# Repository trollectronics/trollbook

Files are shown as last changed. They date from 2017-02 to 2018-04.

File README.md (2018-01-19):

# Trollbook
*Homebrew 68040 palmtop computer* (http://h4xxel.org/electronics/trollbook/)

This is a work-in-progress palmtop (ish) sized clamshell laptop that we've been
working on for a while.

In its current state, it boots up into a BIOS menu capable of doing
a few simple things like browsing a FAT formatted SD-card, flashing its bootrom
from SD-card and excuting programs from SD-card.
One of the included demo programs can play .MOD music files from SD card.

The entire setup uses about 4.3 Watts while running, including
display and backlight.

The hardware specs as of now can be summed up as following:

 - Motorola 68040FE33V CPU, running at 33 MHz
 - Altera Flex10KA FPGA for glue logic and peripherals (video, uart, spi, audio etc.)
 - Atmel attiny48 for scanning keyboard matrix and mouse, interfacing to I2C peripherals
 - 512 kB of SRAM (used for frame buffer, sound buffer and stage 2 BIOS code)
 - 64 MB of SDRAM
 - 800x480 resolution 7" TFT display, driven at 256 colors (from a 16-bpp palette)
 - Stereo audio DAC, 8 bit/channel, samplerate of 48 kHz
 - SD card interface over SPI
 - On-board SPI Flash ROM (512 kB) for BIOS code
 - 7.4 V, 2.2 Ah battery pack with custom balancing circuitry (which sucks)

The (blue) mainboard is a 10x10 cm 4-layer board, designed by us and manufactured by a Chinese PCB fab.
The larger upper board is a CNC milled peripheral board sporting the keyboard, mouse, IO ports and power supplies.
We desperately need to make a proper case...

## This repository
This repository contains the following:
 - Hardware schematics and layout (kicad)
   - Current Rev 2 motherboard
   - Peripheral board
 - VHDL code for the glue logic/peripheral controller FPGA
 - Source code
   - Stage 1 boot, resides in a small ROM block in the FPGA
   - Stage 2 bios, resides in the large SPI rom
   - Demo code for feature testing/demonstration

## Companion projects
The following projects have been developed for the system:
 - The m68k-emu system emulator (https://github.com/slaeshjag/m68k-emu)
 - The trollos operating system (https://github.com/h4xxel/trollos)

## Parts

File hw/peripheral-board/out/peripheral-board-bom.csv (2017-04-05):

Id | Designator | Package | Quantity | Designation | Supplier and ref
1 | J4001 | Connector_Molex_PicoBlade_53047-0510 | 1 | 53047-0510
2 | J7002 | Connector_Molex_PicoBlade_53047-0410 | 1 | 53047-0310
3 | R2001 | R_1206 | 1 | 0R
4 | C1004,C1003,C7001,C7002,C7005,C7012,C8003,C8004 | C_0805 | 8 | 100n
5 | C7014,C7007,C4001,C4002 | C_1206 | 4 | 1u
6 | R1008,R1009,R1010,R9001,R4006,R8002 | R_0805 | 6 | 47k
7 | R1007,R4004,R4003,R4001,R7008,R7004 | R_0805 | 6 | 10k
8 | D2012,D2011,D2010,D2009,D2008,D2007,D2006,D2005,D2004,D2003,D2013,D2001,D2060,D2051,D2052,D2053,D2002,D2054,D2029,D2016,D2017,D2018,D2019,D2020,D2021,D2028,D2023,D2024,D2025,D2026,D2027,D2032,D2015,D2014,D2022,D2034,D2035,D2036,D2037,D2038,D2039,D2040,D2033,D2042,D2043,D2044,D2045,D2046,D2047,D2048,D2050,D2041,D2049,D2056,D2057,D2058,D2059,D2031,D2061,D2062,D2063,D2064,D2065,D2066,D2067,D2068,D2055,D2030 | D_MiniMELF_Standard | 68 | 1N4148
9 | C1002,C1001 | C_0805 | 2 | C
10 | R1005,R7003,R7007,R7005 | R_0805 | 4 | 100k
11 | U1002 | SOT89-3_Housing | 1 | L78L33ACUTR
12 | C4007,C4004 | TantalC_SizeD_EIA-7343_Reflow | 2 | 100u
13 | L4002 | Choke_SMD_6.3x6.3_H3 | 1 | 10u
14 | L4001 | Choke_SMD_6.3x6.3_H3 | 1 | 8u2
15 | C9001,C4003,C4009 | C_1206 | 3 | 10u
16 | Y5001 | Crystal_Watch | 1 | 32768 Hz
17 | D8001 | LED-3MM | 1 | LED_SD
18 | D1001 | LED-3MM | 1 | LED_PWR
19 | D4003 | LED-5MM-3 | 1 | SSL-LX3059IGW-CA
20 | R8003,R1006 | R_0805 | 2 | 1k
21 | Q8001 | SOT-23 | 1 | BSS84LT1G
22 | R4005 | R_1812 | 1 | 0R05
23 | C7004,C7008,C7015 | c_elec_8x6.7 | 3 | 220u
24 | C7003,C7011 | c_elec_6.3x5.8 | 2 | 10u
25 | C4011,C4010 | c_elec_6.3x5.8 | 2 | 100u
26 | L4003 | Choke_SMD_12x12mm_h6mm | 1 | 47u
27 | Q4001 | SOT-23 | 1 | IRLML2244TRPbF
28 | R1003,R1004,R1002,R1001 | R_0805 | 4 | R
29 | RP2001 | R_Cat16-4 | 1 | 10k
30 | CONN9001 | 10056847-XY1LF | 1 | 10056847-XY1LF
31 | U1001 | TQFP-32_7x7mm_Pitch0.8mm | 1 | ATTINY48-A
32 | R4013 | R_0805 | 1 | 13.3k
33 | R4009 | R_0805 | 1 | 412k
34 | R4008 | R_0805 | 1 | 51k
35 | R4007 | R_0805 | 1 | 626k
36 | R4002 | R_0805 | 1 | 330k
37 | R4012 | R_0805 | 1 | 270k
38 | C7006,C7013,C8002 | C_0805 | 3 | 1u
39 | C7016,C7009 | C_0805 | 2 | 1n
40 | C7010,C7017 | C_0805 | 2 | 47n
41 | U7002,U7001 | SOIC-8_3.9x4.9mm_Pitch1.27mm | 2 | LM386
42 | U7003,U7004 | SOIC-8_3.9x4.9mm_Pitch1.27mm | 2 | MCP4011
43 | R7009,R7006 | R_0805 | 2 | 10
44 | J7001 | FCR1295 | 1 | FCR1295
45 | CON8001 | TS-2198-01 | 1 | SD_Card
46 | CON4001 | JACK_ALIM | 1 | BARREL_JACK
47 | C4008 | C_0805 | 1 | 120p
48 | C4005 | C_0805 | 1 | 680n
49 | C4006 | C_1206 | 1 | 2.2u
50 | D4006 | D_MiniMELF_Standard | 1 | 1n4148
51 | D4007 | D_SOD-323 | 1 | NSR0530HT1G
52 | D4005,D4001,D4008,D4002 | D_TUMD2 | 4 | RBE2VA20ATR
53 | U4001 | SOIC-8_3.9x4.9mm_Pitch1.27mm | 1 | AP1509
54 | U4003 | MSOP-12-1EP_3x4mm_Pitch0.65mm | 1 | LT3652
55 | U4002 | SOT-23-5 | 1 | LM27313
56 | C5001,C5002 | C_0603 | 2 | 22p
57 | U5001 | SOIC-8_3.9x4.9mm_Pitch1.27mm | 1 | MCP7940N
58 | SW1001 | SMD-TACT-5.2x5.2x2mm | 1 | Power
59 | U3001 | PSPNUB | 1 | PSPNUB
60 | SW2069,SW2065 | SMD-TACT-5.2x5.2x2mm | 2 | SPACE
61 | P1002 | Socket_Strip_Straight_1x04 | 1 | Power
62 | P1001 | Socket_Strip_Straight_1x29 | 1 | Peripheral Bus
63 | U2003 | SOIC-14_3.9x8.7mm_Pitch1.27mm | 1 | 74HC00
64 | U2001,U2002 | SOIC-16_3.9x9.9mm_Pitch1.27mm | 2 | 4017
65 | SW2001 | SMD-TACT-5.2x5.2x2mm | 1 | 1
66 | SW2002 | SMD-TACT-5.2x5.2x2mm | 1 | 2
67 | SW2003 | SMD-TACT-5.2x5.2x2mm | 1 | 3
68 | SW2004 | SMD-TACT-5.2x5.2x2mm | 1 | 4
69 | SW2005 | SMD-TACT-5.2x5.2x2mm | 1 | 5
70 | SW2006 | SMD-TACT-5.2x5.2x2mm | 1 | 6
71 | SW2007 | SMD-TACT-5.2x5.2x2mm | 1 | 7
72 | SW2009 | SMD-TACT-5.2x5.2x2mm | 1 | 9
73 | SW2035 | SMD-TACT-5.2x5.2x2mm | 1 | A
74 | SW2010 | SMD-TACT-5.2x5.2x2mm | 1 | 0
75 | SW2011 | SMD-TACT-5.2x5.2x2mm | 1 | +
76 | SW2012 | SMD-TACT-5.2x5.2x2mm | 1 | ´
77 | SW2013 | SMD-TACT-5.2x5.2x2mm | 1 | BKSP
78 | SW2014 | SMD-TACT-5.2x5.2x2mm | 1 | TROLL
79 | SW2015 | SMD-TACT-5.2x5.2x2mm | 1 | §
80 | SW2008 | SMD-TACT-5.2x5.2x2mm | 1 | 8
81 | SW2016 | SMD-TACT-5.2x5.2x2mm | 1 | UP
82 | SW2019 | SMD-TACT-5.2x5.2x2mm | 1 | W
83 | SW2020 | SMD-TACT-5.2x5.2x2mm | 1 | E
84 | SW2021 | SMD-TACT-5.2x5.2x2mm | 1 | R
85 | SW2022 | SMD-TACT-5.2x5.2x2mm | 1 | T
86 | SW2023 | SMD-TACT-5.2x5.2x2mm | 1 | Y
87 | SW2024 | SMD-TACT-5.2x5.2x2mm | 1 | U
88 | SW2033 | SMD-TACT-5.2x5.2x2mm | 1 | LEFT
89 | SW2017 | SMD-TACT-5.2x5.2x2mm | 1 | RMB
90 | SW2027 | SMD-TACT-5.2x5.2x2mm | 1 | P
91 | SW2028 | SMD-TACT-5.2x5.2x2mm | 1 | Å
92 | SW2029 | SMD-TACT-5.2x5.2x2mm | 1 | ¨
93 | SW2030 | SMD-TACT-5.2x5.2x2mm | 1 | RETURN
94 | SW2031 | SMD-TACT-5.2x5.2x2mm | 1 | ALT_GR
95 | SW2032 | SMD-TACT-5.2x5.2x2mm | 1 | <
96 | SW2034 | SMD-TACT-5.2x5.2x2mm | 1 | MMB
97 | SW2025 | SMD-TACT-5.2x5.2x2mm | 1 | I
98 | SW2037 | SMD-TACT-5.2x5.2x2mm | 1 | D
99 | SW2038 | SMD-TACT-5.2x5.2x2mm | 1 | F
100 | SW2039 | SMD-TACT-5.2x5.2x2mm | 1 | G
101 | SW2040 | SMD-TACT-5.2x5.2x2mm | 1 | H
102 | SW2041 | SMD-TACT-5.2x5.2x2mm | 1 | J
103 | SW2042 | SMD-TACT-5.2x5.2x2mm | 1 | K
104 | SW2043 | SMD-TACT-5.2x5.2x2mm | 1 | L
105 | SW2018 | SMD-TACT-5.2x5.2x2mm | 1 | Q
106 | SW2045 | SMD-TACT-5.2x5.2x2mm | 1 | Ä
107 | SW2046 | SMD-TACT-5.2x5.2x2mm | 1 | '
108 | SW2047 | SMD-TACT-5.2x5.2x2mm | 1 | ESC
109 | SW2048 | SMD-TACT-5.2x5.2x2mm | 1 | TAB
110 | SW2049 | SMD-TACT-5.2x5.2x2mm | 1 | ALT
111 | SW2050 | SMD-TACT-5.2x5.2x2mm | 1 | DOWN
112 | SW2052 | SMD-TACT-5.2x5.2x2mm | 1 | SHIFT_L
113 | SW2026 | SMD-TACT-5.2x5.2x2mm | 1 | O
114 | SW2044 | SMD-TACT-5.2x5.2x2mm | 1 | Ö
115 | SW2061 | SMD-TACT-5.2x5.2x2mm | 1 | .
116 | SW2053 | SMD-TACT-5.2x5.2x2mm | 1 | Z
117 | SW2054 | SMD-TACT-5.2x5.2x2mm | 1 | X
118 | SW2055 | SMD-TACT-5.2x5.2x2mm | 1 | C
119 | SW2056 | SMD-TACT-5.2x5.2x2mm | 1 | V
120 | SW2057 | SMD-TACT-5.2x5.2x2mm | 1 | B
121 | SW2058 | SMD-TACT-5.2x5.2x2mm | 1 | N
122 | SW2059 | SMD-TACT-5.2x5.2x2mm | 1 | M
123 | SW2051 | SMD-TACT-5.2x5.2x2mm | 1 | LMB
124 | SW2036 | SMD-TACT-5.2x5.2x2mm | 1 | S
125 | SW2062 | SMD-TACT-5.2x5.2x2mm | 1 | -
126 | SW2063 | SMD-TACT-5.2x5.2x2mm | 1 | SHIFT_R
127 | SW2064 | SMD-TACT-5.2x5.2x2mm | 1 | FN_R
128 | SW2066 | SMD-TACT-5.2x5.2x2mm | 1 | FN_L
129 | SW2067 | SMD-TACT-5.2x5.2x2mm | 1 | RIGHT
130 | SW2068 | SMD-TACT-5.2x5.2x2mm | 1 | CTRL
131 | SW2060 | SMD-TACT-5.2x5.2x2mm | 1 | ,

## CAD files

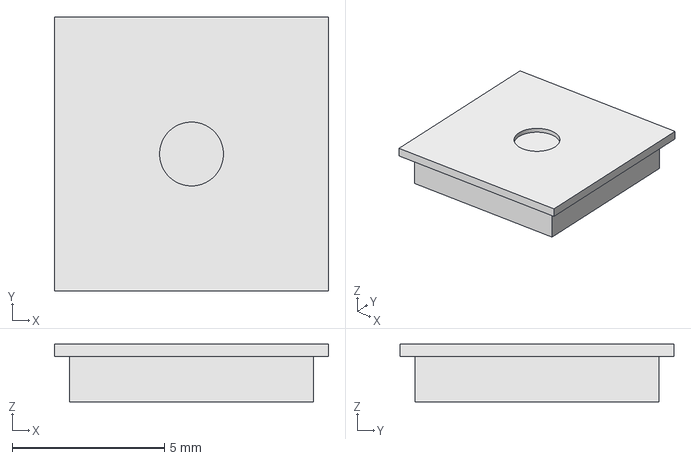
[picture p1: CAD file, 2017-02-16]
cad/keyboard_prototype/keycap.fcstd
9.00 x 9.00 x 1.90 mm

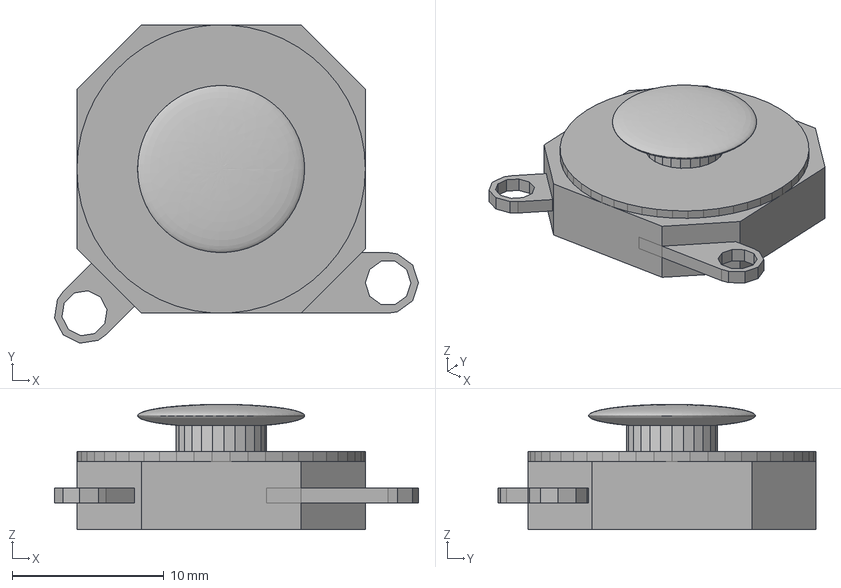
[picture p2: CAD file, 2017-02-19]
hw/peripheral-board/3d/pspnub.step
24.0 x 21.0 x 8.25 mm

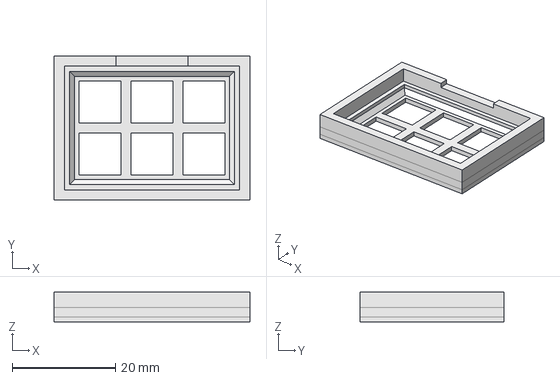
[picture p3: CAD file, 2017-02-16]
cad/keyboard_prototype/keyboard_frame.fcstd
38.0 x 28.0 x 5.80 mm

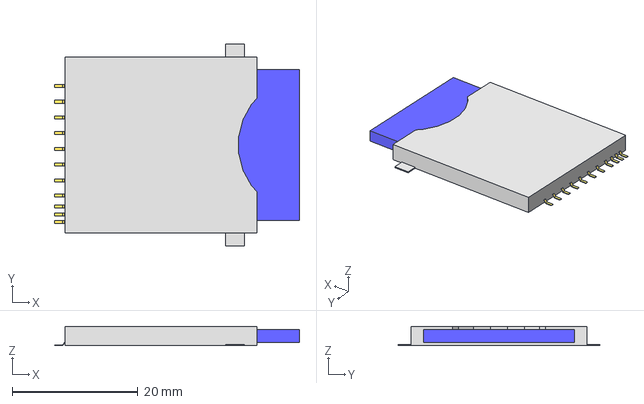
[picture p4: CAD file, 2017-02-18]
hw/peripheral-board/3d/SD-RSMT-2-MQ.step
39.0 x 32.1 x 3.10 mm

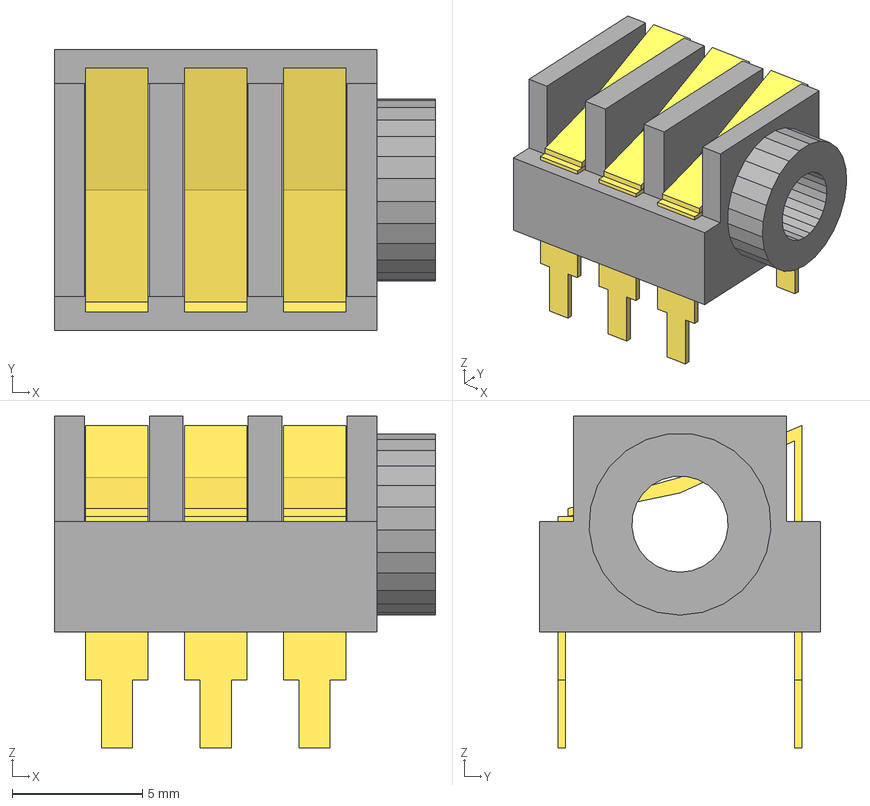
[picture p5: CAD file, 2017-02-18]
hw/peripheral-board/3d/FCR1295.step
14.7 x 10.8 x 12.8 mm

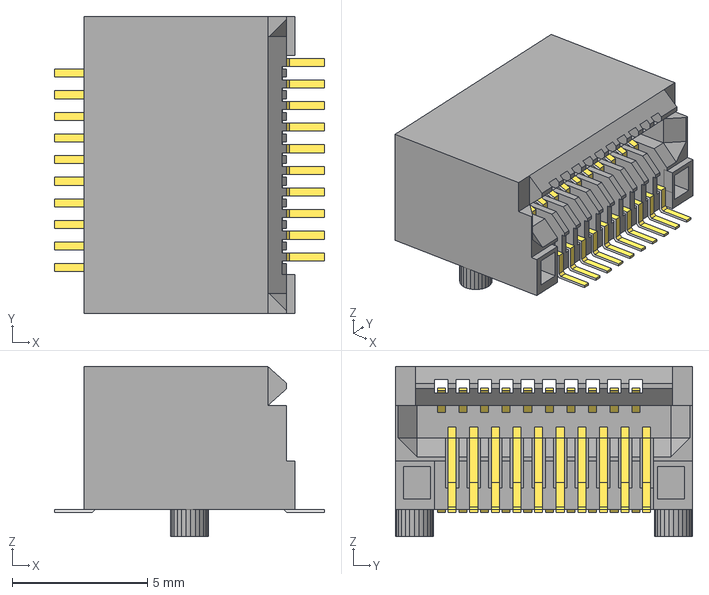
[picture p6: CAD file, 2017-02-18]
hw/peripheral-board/3d/10056847-XY1LF.step
10.0 x 11.0 x 6.30 mm

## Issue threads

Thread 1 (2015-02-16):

sram has wrong footprint

h4xxel, 2015-02-16:
i am retarded

Closed 2016-04-02.

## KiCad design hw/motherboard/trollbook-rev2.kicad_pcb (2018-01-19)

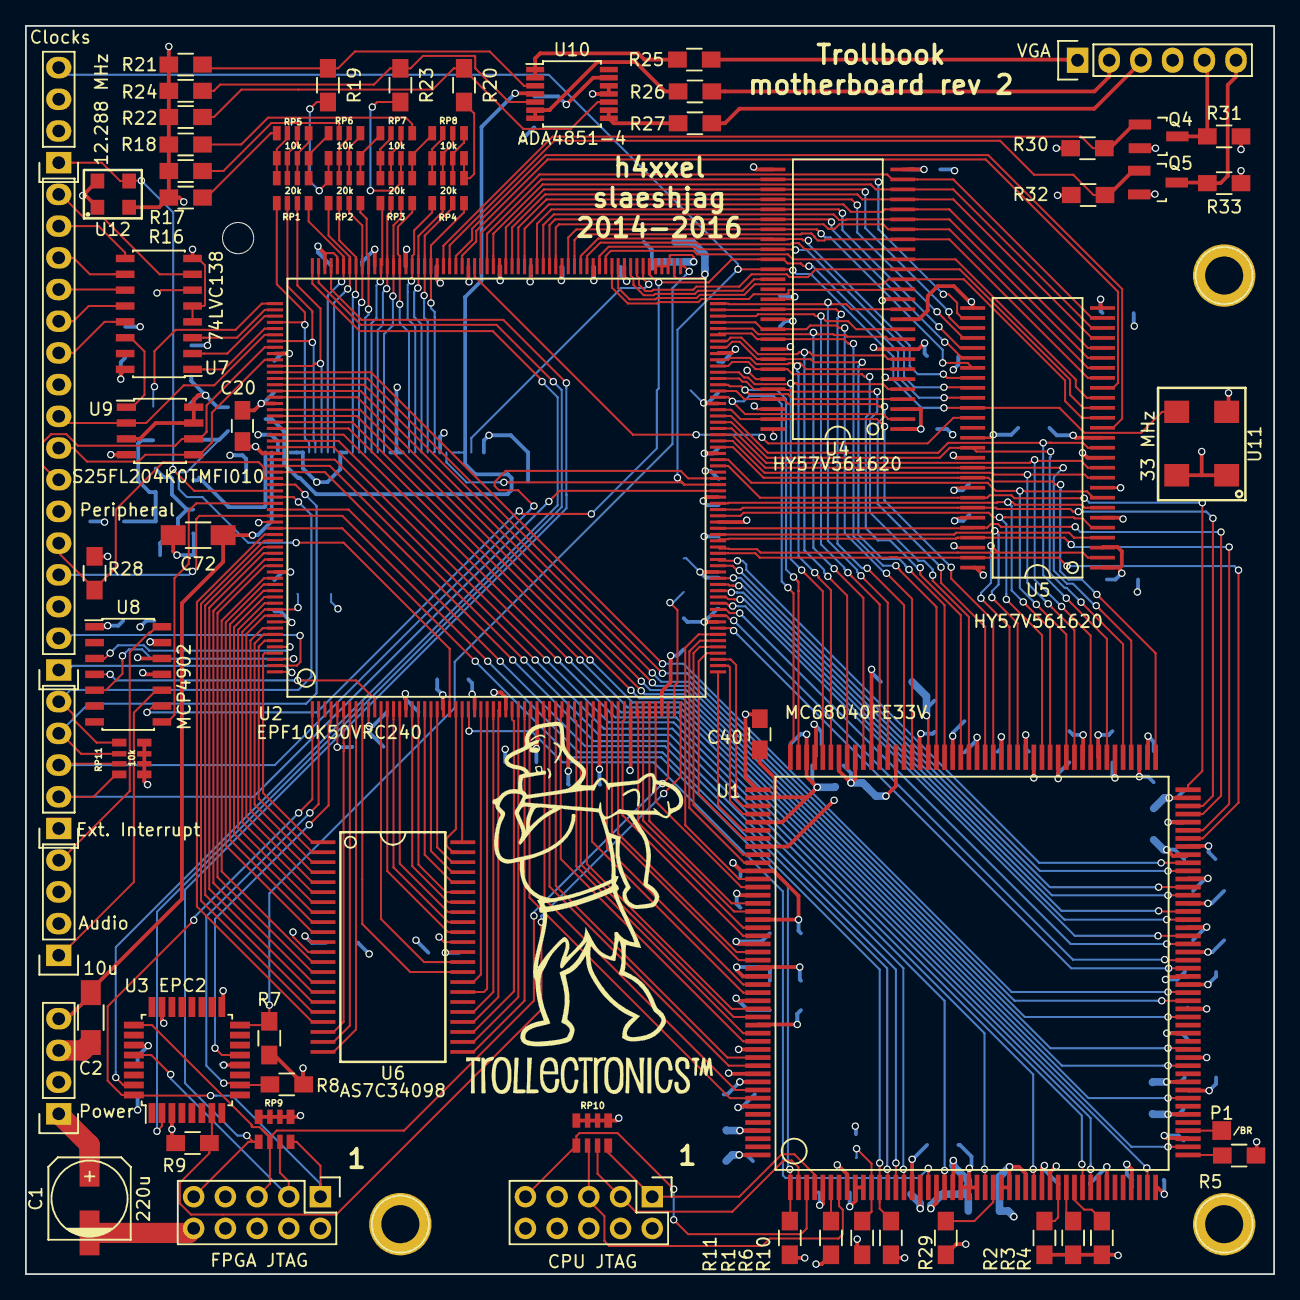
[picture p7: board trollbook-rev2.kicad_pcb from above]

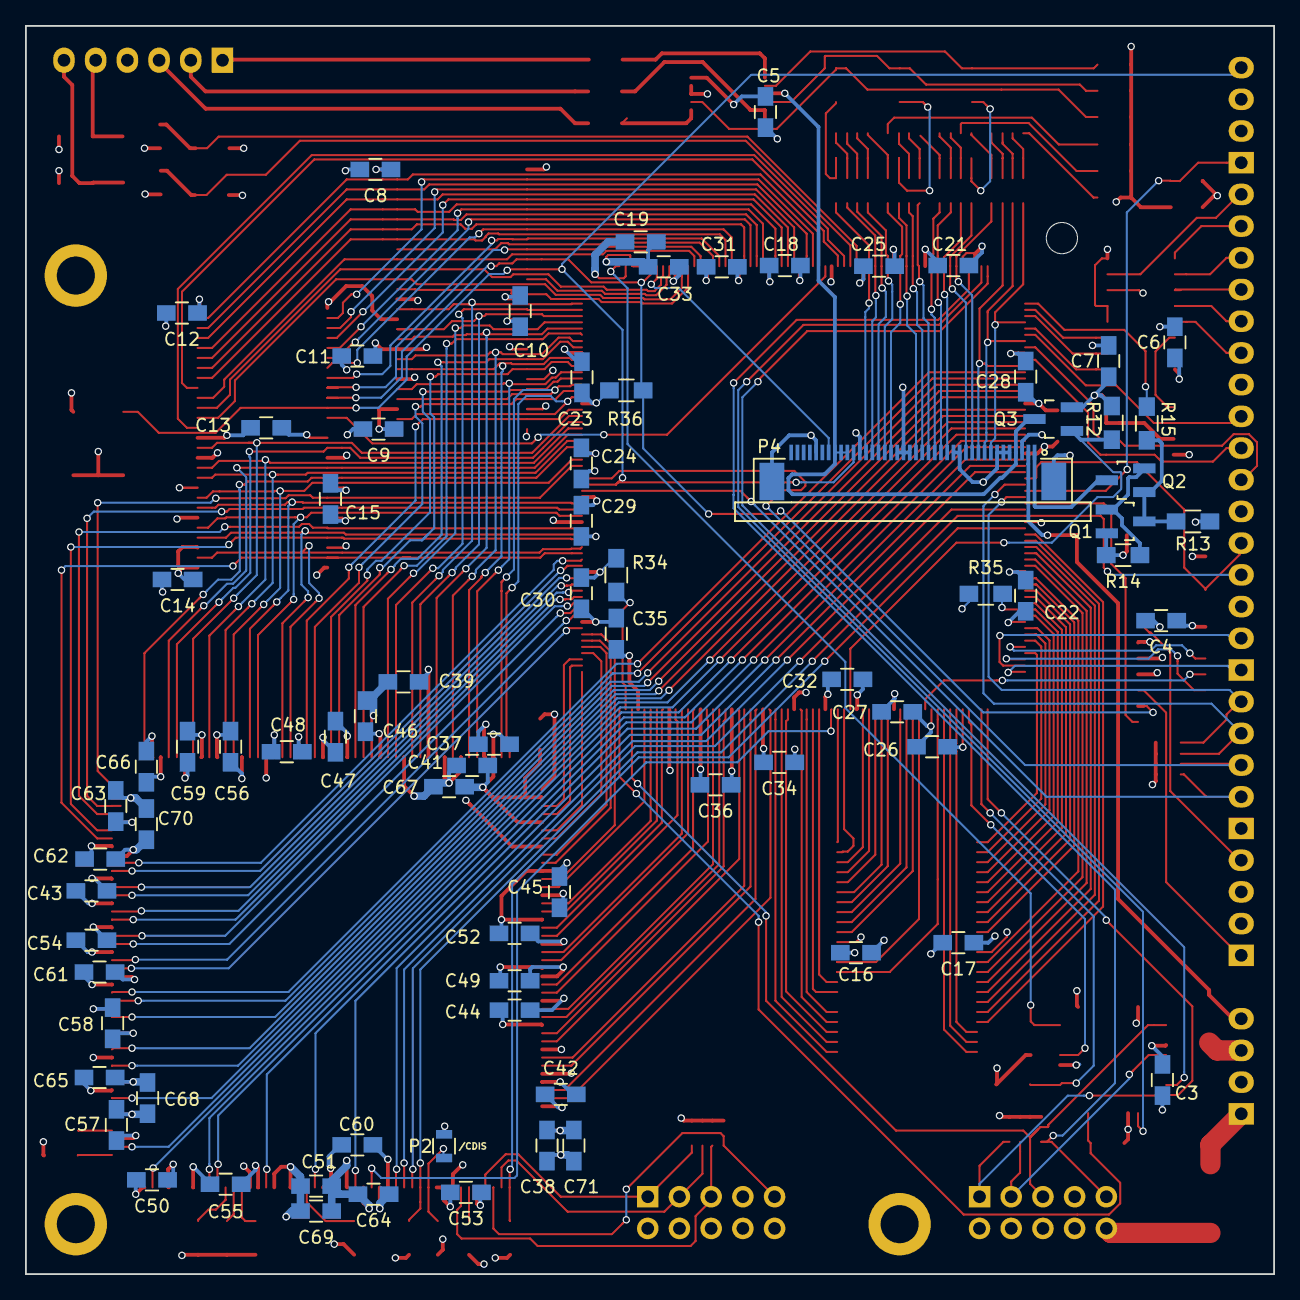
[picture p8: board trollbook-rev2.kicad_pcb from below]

Board: 4 copper layers, 100.0 x 100.0 mm, 147 parts (79 on the bottom side), 258 nets.

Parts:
C1: 220u; c_elec_6.3x7.7
C2: 10u; C_1206_HandSoldering
C3, C4, C5, C6, C7, C8, C9, C10, C11, C12, C13, C14, C15, C16, C17, C18, C19, C20, C21, C22, C23, C24, C25, C26, C27, C28, C29, C30, C31, C32, C33, C34, C35, C36, C67, C68, C69, C70, C71: 100n; C_0805_HandSoldering
C37, C38, C39, C40, C41, C42, C43, C44, C45, C46, C47, C48, C49, C50, C51, C52, C53, C54, C55, C56, C57, C58, C59, C60, C61, C62, C63, C64, C65, C66: 10n; C_0805_HandSoldering
C72: 1u; C_1206_HandSoldering
CON1: FPGA JTAG; Pin_Header_Straight_2x05
CON2: CPU JTAG; Pin_Header_Straight_2x05
P1: /BR; Measurement_Point_Square-SMD-Pad_Small
P2: /CDIS; R_0805
P3: Audio; Pin_Header_Straight_1x04
P4: ER-CON40HT-1
P5: Power; Pin_Header_Straight_1x04
P6: Peripheral; Pin_Header_Straight_1x16
P7: VGA; Pin_Header_Straight_1x06
P8: Clocks; Pin_Header_Straight_1x04
P9: Ext. Interrupt; Pin_Header_Straight_1x05
Q1, Q2, Q4, Q5: 2N7002E; SOT-23_Handsoldering
Q3: DMP3030SN-7; SOT-23_Handsoldering
R1, R10, R11, R15, R29, R30, R31, R32, R33: R; R_0805_HandSoldering
R2, R3, R4, R5, R6, R12, R16, R17, R18, R34, R35, R36: 10k; R_0805_HandSoldering
R7, R8, R9, R28: 1k; R_0805_HandSoldering
R13: 470k; R_0805_HandSoldering
R14: 20R; R_0805_HandSoldering
R19, R20, R23: 560k; R_0805_HandSoldering
R21, R22, R24: 180k; R_0805_HandSoldering
R25, R26, R27: 75; R_0805_HandSoldering
RP1, RP2, RP3, RP4: 20k; RPACK8_SMD
RP5, RP6, RP7, RP8, RP9, RP10, RP11: 10k; RPACK8_SMD
U1: MC68040FE33V; QFP-184
U2: EPF10K50VRC240; RQFP-240
U3: EPC2; TQFP-32_7x7mm_Pitch0.8mm
U4, U5: HY57V561620; TSOP54
U6: AS7C34098; TSOP44
U7: 74LVC138; SOIC-16_3.9x9.9mm_Pitch1.27mm
U8: MCP4902; SOIC-14_3.9x8.7mm_Pitch1.27mm
U9: S25FL204K0TMFI010; SOIC-8_3.9x4.9mm_Pitch1.27mm
U10: ADA4851-4; TSSOP-14_4.4x5mm_Pitch0.65mm
U11: 33 MHz; OSC-VCC1-B3B
U12: 12.288 MHz; OSC-ASFLMB

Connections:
+3V3: C1.1, C3.1, C4.1, C5.1, C6.1, C7.1, C8.1, C9.1, C10.1, C11.1, C12.1, C13.1, C14.1, C15.1, C16.1, C17.1, C18.1, C19.1, C20.1, C21.1, C22.1, C23.2, C24.2, C25.2, C26.2, C27.2, C28.1, C29.1, C30.1, C31.1, C32.1, C33.2, C34.2, C35.2, C36.2, C37.1, C38.1, C39.1, C40.1, C41.1, C42.2, C43.2, C44.2, C45.2, C46.2, C47.1, C48.1, C49.1, C50.1, C51.1, C52.2, C53.2, C54.2, C55.2, C56.2, C57.1, C58.1, C59.1, C60.1, C61.1, C62.2, C63.2, C64.2, C65.2, C66.2, C67.1, C68.1, C69.1, C70.1, C71.1, CON1.4, CON2.4, P5.1, Q3.2, R5.1, R6.2, R7.1, R8.1, R9.1, R11.1, R15.1, R29.1, R30.2, R31.2, R32.2, R33.2, R34.1, R35.1, RP9.1, RP9.2, RP9.3, RP9.4, RP10.1, RP10.2, RP10.3, RP10.4, RP11.1, RP11.2, RP11.3, RP11.4, U1.9, U1.10, U1.16, U1.19, U1.21, U1.32, U1.43, U1.49, U1.56, U1.62, U1.69, U1.75, U1.81, U1.84, U1.88, U1.94, U1.100, U1.102, U1.109, U1.115, U1.122, U1.128, U1.136, U1.140, U1.143, U1.149, U1.155, U1.161, U1.168, U1.175, U1.181, U2.5, U2.16, U2.27, U2.37, U2.47, U2.57, U2.77, U2.89, U2.96, U2.112, U2.122, U2.130, U2.140, U2.150, U2.160, U2.170, U2.189, U2.205, U2.224, U3.3, U3.17, U3.23, U3.27, U4.1, U4.3, U4.9, U4.14, U4.27, U4.43, U4.49, U5.1, U5.3, U5.9, U5.14, U5.27, U5.43, U5.49, U6.11, U6.33, U7.6, U7.16, U8.1, U8.11, U8.13, U9.3, U9.7, U9.8, U10.13, U11.1, U11.4, U12.1, U12.4
/A0: U1.70, U2.68
/A1: U1.71, U2.70
/A2: U1.73, U2.71
/A3: U1.74, U2.72
/A4: U1.76, U2.73
/A5: U1.77, U2.74
/A6: U1.79, U2.75
/A7: U1.80, U2.76
/A8: U1.82, U2.78
/A9: U1.83, U2.79
/A10: U1.173, U2.39
/A11: U1.172, U2.40
/A12: U1.170, U2.41
/A13: U1.169, U2.43
/A14: U1.167, U2.44
/A15: U1.166, U2.45
/A16: U1.164, U2.46
/A17: U1.163, U2.48
/A18: U1.160, U2.49
/A19: U1.159, U2.50
/A20: U1.157, U2.51
/A21: U1.156, U2.53
/A22: U1.154, U2.54
/A23: U1.153, U2.55
/A24: U1.151, U2.56
/A25: U1.150, U2.67
/A26: U1.148, U2.66
/A27: U1.147, U2.65
/A28: U1.145, U2.64
/A29: U1.144, U2.61
/A30: U1.142, U2.62
/A31: U1.141, U2.63
/AUDIOL: P3.4, U8.14
/AUDIOR: P3.1, U8.10
/CLK12: P8.1, U2.211, U12.3
/CLK33: P4.30, P8.4, U2.91, U4.38, U5.38, U11.3
/CONF_CLK: U2.179, U3.2
/CONF_CS: R8.2, U2.2, U3.10
/CONF_DATA: U2.180, U3.31
/CONF_INIT: R7.2, U2.121, U3.16
/CONF_OE: R9.2, U2.60, U3.7
/CONF_TDO: CON1.3, RP9.7, U3.28
/CPUBB: R5.2, U1.47
/CPUBG: R4.2, U1.36
/CPUBR: P1.1, U1.50
/CPUCDIS: P2.1, R6.1, U1.11
/CPUCLK: U1.18, U2.26
/CPUIPL0: U1.15, U2.207
/CPUIPL1: U1.14, U2.208
/CPUIPL2: U1.13, U2.214
/CPULFO: U1.20, U2.206
/CPULOC: R1.2, U1.6
/CPURSTI: P6.4, R10.2, U1.12, U2.215
/CPURSTO: R11.2, U1.1, U2.217
/CPURW: U1.58, U2.196
/CPUSC0: R2.2, U1.34
/CPUSC1: R3.2, U1.35
/CPUSCD: U1.25, U2.204
/CPUSIZ0: U1.60, U2.195
/CPUSIZ1: U1.54, U2.198
/CPUTA: U1.38, U2.201
/CPUTBI: U1.31, U2.203
/CPUTCK: CON2.1, RP10.8, U1.4
/CPUTDI: CON2.9, RP10.5, U1.3
/CPUTDO: CON2.3, RP10.7, U1.2
/CPUTEA: U1.37, U2.202
/CPUTIP: U1.45, U2.200
/CPUTM0: U1.64, U2.194
/CPUTM1: U1.66, U2.193
/CPUTM2: U1.67, U2.192
/CPUTMS: CON2.5, RP10.6, U1.7
/CPUTP: U1.48, U2.199
/CPUTT0: U1.177, U2.36
/CPUTT1: U1.176, U2.38
/D0: U1.138, U2.105, U4.2
/D1: U1.137, U2.107, U4.4
/D2: U1.134, U2.109, U4.5
/D3: U1.133, U2.111, U4.7
/D4: U1.131, U2.114, U4.8
/D5: U1.129, U2.116, U4.10
/D6: U1.127, U2.118, U4.11
/D7: U1.126, U2.120, U4.13
/D8: U1.124, U2.119, U4.42
/D9: U1.123, U2.117, U4.44
/D10: U1.120, U2.115, U4.45
/D11: U1.119, U2.113, U4.47
/D12: U1.117, U2.110, U4.48
/D13: U1.116, U2.108, U4.50
/D14: U1.114, U2.106, U4.51
/D15: U1.113, U2.103, U4.53
/D16: U1.111, U2.81, U5.2
/D17: U1.110, U2.83, U5.4
/D18: U1.107, U2.86, U5.5
/D19: U1.106, U2.88, U5.7
/D20: U1.104, U2.95, U5.8
/D21: U1.103, U2.98, U5.10
/D22: U1.101, U2.100, U5.11
/D23: U1.99, U2.102, U5.13
/D24: U1.97, U2.101, U5.42
/D25: U1.96, U2.99, U5.44
/D26: U1.93, U2.97, U5.45
/D27: U1.92, U2.94, U5.47
/D28: U1.90, U2.87, U5.48
/D29: U1.89, U2.84, U5.50
/D30: U1.87, U2.82, U5.51
/D31: U1.86, U2.80, U5.53
/EXTINT0: P9.2, RP11.8, U2.90
/EXTINT1: P9.3, RP11.7, U2.92
/EXTINT2: P9.4, RP11.6, U2.210
/EXTINT3: P9.5, RP11.5, U2.212
/FPGA_TCK: CON1.1, RP9.8, U2.1, U3.32
/FPGA_TDI: CON1.9, RP9.5, U2.177
/FPGA_TDO: U2.4, U3.13
/FPGA_TMS: CON1.5, RP9.6, U2.58, U3.25
/LLA1: U2.237, U6.1
/LLA2: U2.235, U6.2
/LLA3: U2.234, U6.3
/LLA4: U2.233, U6.4
/LLA5: U2.231, U6.5
/LLA6: U2.219, U6.18
/LLA7: U2.218, U6.19
/LLA8: U2.6, U6.20
/LLA9: U2.7, U6.21
/LLA10: U2.8, U6.22
/LLA11: U2.35, U6.23
/LLA12: U2.34, U6.24
/LLA13: U2.33, U6.25
/LLA14: U2.31, U6.26
/LLA15: U2.30, U6.27
/LLA16: U2.21, U6.42
/LLA17: U2.24, U6.43
/LLA18: U2.25, U6.44
/LLCE: R35.2, U2.230, U6.6
/LLD0: U2.229, U6.7
/LLD1: U2.228, U6.8
/LLD2: U2.227, U6.9
/LLD3: U2.226, U6.10
/LLD4: U2.225, U6.13
/LLD5: U2.223, U6.14
/LLD6: U2.222, U6.15
/LLD7: U2.221, U6.16
/LLD8: U2.29, U6.29
/LLD9: U2.28, U6.30
/LLD10: U2.9, U6.31
/LLD11: U2.12, U6.32
/LLD12: U2.13, U6.35
/LLD13: U2.14, U6.36
/LLD14: U2.15, U6.37
/LLD15: U2.17, U6.38
/LLLB: U2.18, U6.39
/LLOE: U2.20, U6.41
/LLUB: U2.19, U6.40
/LLWE: U2.220, U6.17
/PWRON_RESET: P6.5, R28.1, U2.209
/RAM0CS: U2.136, U4.19
/RAM0LDQM: U2.132, U4.15
/RAM0UDQM: U2.129, U4.39
/RAM1CS: U2.156, U5.19
/RAM1LDQM: U2.157, U5.15
/RAM1UDQM: U2.154, U5.39
/RAMA0: U2.146, U4.23, U5.23
/RAMA1: U2.148, U4.24, U5.24
/RAMA2: U2.151, U4.25, U5.25
/RAMA3: U2.153, U4.26, U5.26
/RAMA4: U2.152, U4.29, U5.29
/RAMA5: U2.149, U4.30, U5.30
/RAMA6: U2.147, U4.31, U5.31
/RAMA7: U2.144, U4.32, U5.32
/RAMA8: U2.142, U4.33, U5.33
/RAMA9: U2.139, U4.34, U5.34
/RAMA10: U2.143, U4.22, U5.22
/RAMA11: U2.137, U4.35, U5.35
/RAMA12: U2.134, U4.36, U5.36
/RAMB0: U2.138, U4.20, U5.20
/RAMB1: U2.141, U4.21, U5.21
/RAMCAS: U2.128, U4.17, U5.17
/RAMCKE: R36.1, U2.126, U4.37, U5.37, U8.9
/RAMRAS: U2.133, U4.18, U5.18
/RAMWE: U2.131, U4.16, U5.16
/SNDSYNC: U2.213, U8.8
/SPI0CLK: P6.7, U2.188, U9.6
/SPI0MISO: P6.9, U2.186, U9.2
/SPI0MOSI: P6.8, U2.190, U9.5
/SPI0SS1: U7.14, U9.1
/SPI0SS2: P6.11, U7.13
/SPI0SS3: P6.12, U7.12
/SPI0SS4: P6.13, U7.11
/SPI0SS5: P6.14, U7.10
/SPI0SS6: P6.15, U7.9
/SPI0SS7: P6.16, U7.7
/SPI0SSBIT0: U2.185, U7.1
/SPI0SSBIT1: U2.183, U7.2
/SPI0SSBIT2: U2.182, U7.3
/SPI1CLK: U2.11, U8.4
/SPI1MOSI: U2.238, U8.5
/SPI1SS: U2.236, U8.3
/UARTRX: P6.1, U2.240
/UARTTX: P6.2, U2.239
/VGAB0: P4.24, RP3.4, U2.166
/VGAB1: P4.25, RP4.1, U2.164
/VGAB2: P4.26, RP4.2, U2.163
/VGAB3: P4.27, RP4.3, U2.162
/VGAB4: P4.28, RP4.4, U2.161
/VGADEN: P4.34, U2.127
/VGADISP: P4.4, P4.31, P4.32, P4.33, Q3.3, U10.4
/VGAG0: P4.15, RP2.2, U2.173
/VGAG1: P4.16, RP2.3, U2.172
/VGAG2: P4.17, RP2.4, U2.171
/VGAG3: P4.18, RP3.1, U2.169
/VGAG4: P4.19, RP3.2, U2.168
/VGAG5: P4.20, RP3.3, U2.167
/VGAHSYNC: Q4.1, R30.1, U2.159
/VGALED_ANODE: C2.1, C72.1, P4.2, P5.4
/VGALED_CATHODE: P4.1, Q2.3
/VGALED_PWM: R12.2, U2.181
/VGAPWR: Q3.1, R15.2, U2.23
/VGAR0: P4.8, RP1.1, U2.184
/VGAR1: P4.9, RP1.2, U2.187
/VGAR2: P4.10, RP1.3, U2.191
/VGAR3: P4.11, RP1.4, U2.175
/VGAR4: P4.12, RP2.1, U2.174
/VGAVSYNC: Q5.1, R32.1, U2.158
GND: C1.2, C2.2, C3.2, C4.2, C5.2, C6.2, C7.2, C8.2, C9.2, C10.2, C11.2, C12.2, C13.2, C14.2, C15.2, C16.2, C17.2, C18.2, C19.2, C20.2, C21.2, C22.2, C23.1, C24.1, C25.1, C26.1, C27.1, C28.2, C29.2, C30.2, C31.2, C32.2, C33.1, C34.1, C35.1, C36.1, C37.2, C38.2, C39.2, C40.2, C41.2, C42.1, C43.1, C44.1, C45.1, C46.1, C47.2, C48.2, C49.2, C50.2, C51.2, C52.1, C53.1, C54.1, C55.1, C56.1, C57.2, C58.2, C59.2, C60.2, C61.2, C62.1, C63.1, C64.1, C65.1, C66.1, C67.2, C68.2, C69.2, C70.2, C71.2, C72.2, CON1.2, CON1.10, CON2.2, CON2.10, P2.2, P3.2, P3.3, P4.3, P4.5, P4.6, P4.7, P4.13, P4.14, P4.21, P4.22, P4.23, P4.29, P4.36, P4.GND, P5.2, P5.3, P6.3, P6.6, P6.10, P7.4, P8.2, P8.3, P9.1, Q1.2, Q4.2, Q5.2, R1.1, R2.1, R3.1, R4.1, R10.1, R13.2, R14.2, R16.1, R17.1, R18.1, R21.2, R22.2, R24.2, R28.2, R36.2, U1.5, U1.8, U1.17, U1.22, U1.23, U1.24, U1.27, U1.28, U1.30, U1.33, U1.40, U1.46, U1.52, U1.55, U1.59, U1.65, U1.68, U1.72, U1.78, U1.85, U1.91, U1.95, U1.98, U1.105, U1.108, U1.112, U1.118, U1.121, U1.125, U1.130, U1.132, U1.135, U1.139, U1.146, U1.152, U1.158, U1.162, U1.165, U1.171, U1.174, U1.178, U1.184, U2.10, U2.22, U2.32, U2.42, U2.52, U2.69, U2.85, U2.93, U2.104, U2.123, U2.124, U2.125, U2.135, U2.145, U2.155, U2.165, U2.176, U2.178, U2.197, U2.216, U2.232, U3.12, U4.6, U4.12, U4.28, U4.41, U4.46, U4.52, U4.54, U5.6, U5.12, U5.28, U5.41, U5.46, U5.52, U5.54, U6.12, U6.34, U7.4, U7.5, U7.8, U8.12, U9.4, U10.11, U10.12, U11.2, U12.2
unnamed: P7.1, R25.1
unnamed: P7.2, R26.1
unnamed: P7.3, R27.1
unnamed: P7.5, Q4.3, R31.1
unnamed: P7.6, Q5.3, R33.1
unnamed: Q1.1, Q2.2, R14.1
unnamed: Q1.3, Q2.1, R12.1, R13.1
unnamed: R16.2, RP5.8
unnamed: R17.2, RP6.7
unnamed: R18.2, RP7.5
unnamed: R19.1, R21.1, U10.3
unnamed: R19.2, RP2.8, RP6.1
unnamed: R20.1, R22.1, U10.10
unnamed: R20.2, RP4.5, RP8.4
unnamed: R23.1, R24.1, U10.5
unnamed: R23.2, RP3.6, RP7.3
unnamed: R25.2, U10.1, U10.2
unnamed: R26.2, U10.6, U10.7
unnamed: R27.2, U10.8, U10.9
unnamed: R29.2, U1.26
unnamed: R34.2, U2.59
unnamed: RP1.5, RP5.4, RP6.8
unnamed: RP1.6, RP5.3, RP5.5
unnamed: RP1.7, RP5.2, RP5.6
unnamed: RP1.8, RP5.1, RP5.7
unnamed: RP2.5, RP6.4, RP7.8
unnamed: RP2.6, RP6.3, RP6.5
unnamed: RP2.7, RP6.2, RP6.6
unnamed: RP3.5, RP7.4, RP8.8
unnamed: RP3.7, RP7.2, RP7.6
unnamed: RP3.8, RP7.1, RP7.7
unnamed: RP4.6, RP8.3, RP8.5
unnamed: RP4.7, RP8.2, RP8.6
unnamed: RP4.8, RP8.1, RP8.7

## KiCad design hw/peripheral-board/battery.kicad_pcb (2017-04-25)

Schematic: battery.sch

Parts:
BT5001, BT5002: LiPo 2200mAh 51x68x5; Socket_Strip_Straight_1x02_Pitch1.27mm
J1001: CONN_01X03; Socket_Strip_Straight_1x03_Pitch2.54mm
Q5001, Q5002: IRLML2244TRPbF; SOT-23
R5001, R5006: 10k; R_0805
R5002, R5007: 150k; R_0805
R5003, R5004, R5008, R5009: 40R; R_0805
R5005, R5010: 220k; R_0805
RV5001, RV5002: 47k; 3364W
TH5001: 10k; CP_Radial_Tantal_D4.5mm_P2.50mm
U5002, U5003: TL431; SOT-23

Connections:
/B+: BT5001.1, J1001.3, Q5001.2, R5001.1, R5002.1
/B-: BT5002.2, J1001.1, R5008.2, R5009.2, R5010.2, TH5001.2, U5003.3
/NTC: J1001.2, TH5001.1
unnamed: BT5001.2, BT5002.1, Q5002.2, R5003.2, R5004.2, R5005.2, R5006.1, R5007.1, U5002.3
unnamed: Q5001.1, R5001.2, U5002.1
unnamed: Q5001.3, R5003.1, R5004.1
unnamed: Q5002.1, R5006.2, U5003.1
unnamed: Q5002.3, R5008.1, R5009.1
unnamed: R5002.2, RV5001.1
unnamed: R5005.1, RV5001.3
unnamed: R5007.2, RV5002.1
unnamed: R5010.1, RV5002.3
unnamed: RV5001.2, U5002.2
unnamed: RV5002.2, U5003.2

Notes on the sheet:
2 × 1/4 W
505168
pot: 3364W-1-503E

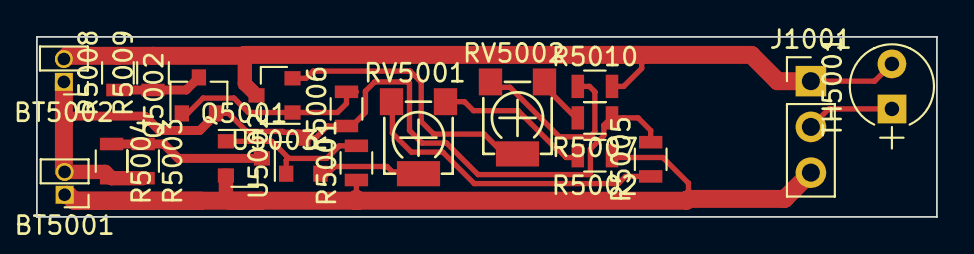
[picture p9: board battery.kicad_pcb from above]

Board: 2 copper layers, 50.0 x 10.0 mm, 20 parts (0 on the bottom side), 14 nets.

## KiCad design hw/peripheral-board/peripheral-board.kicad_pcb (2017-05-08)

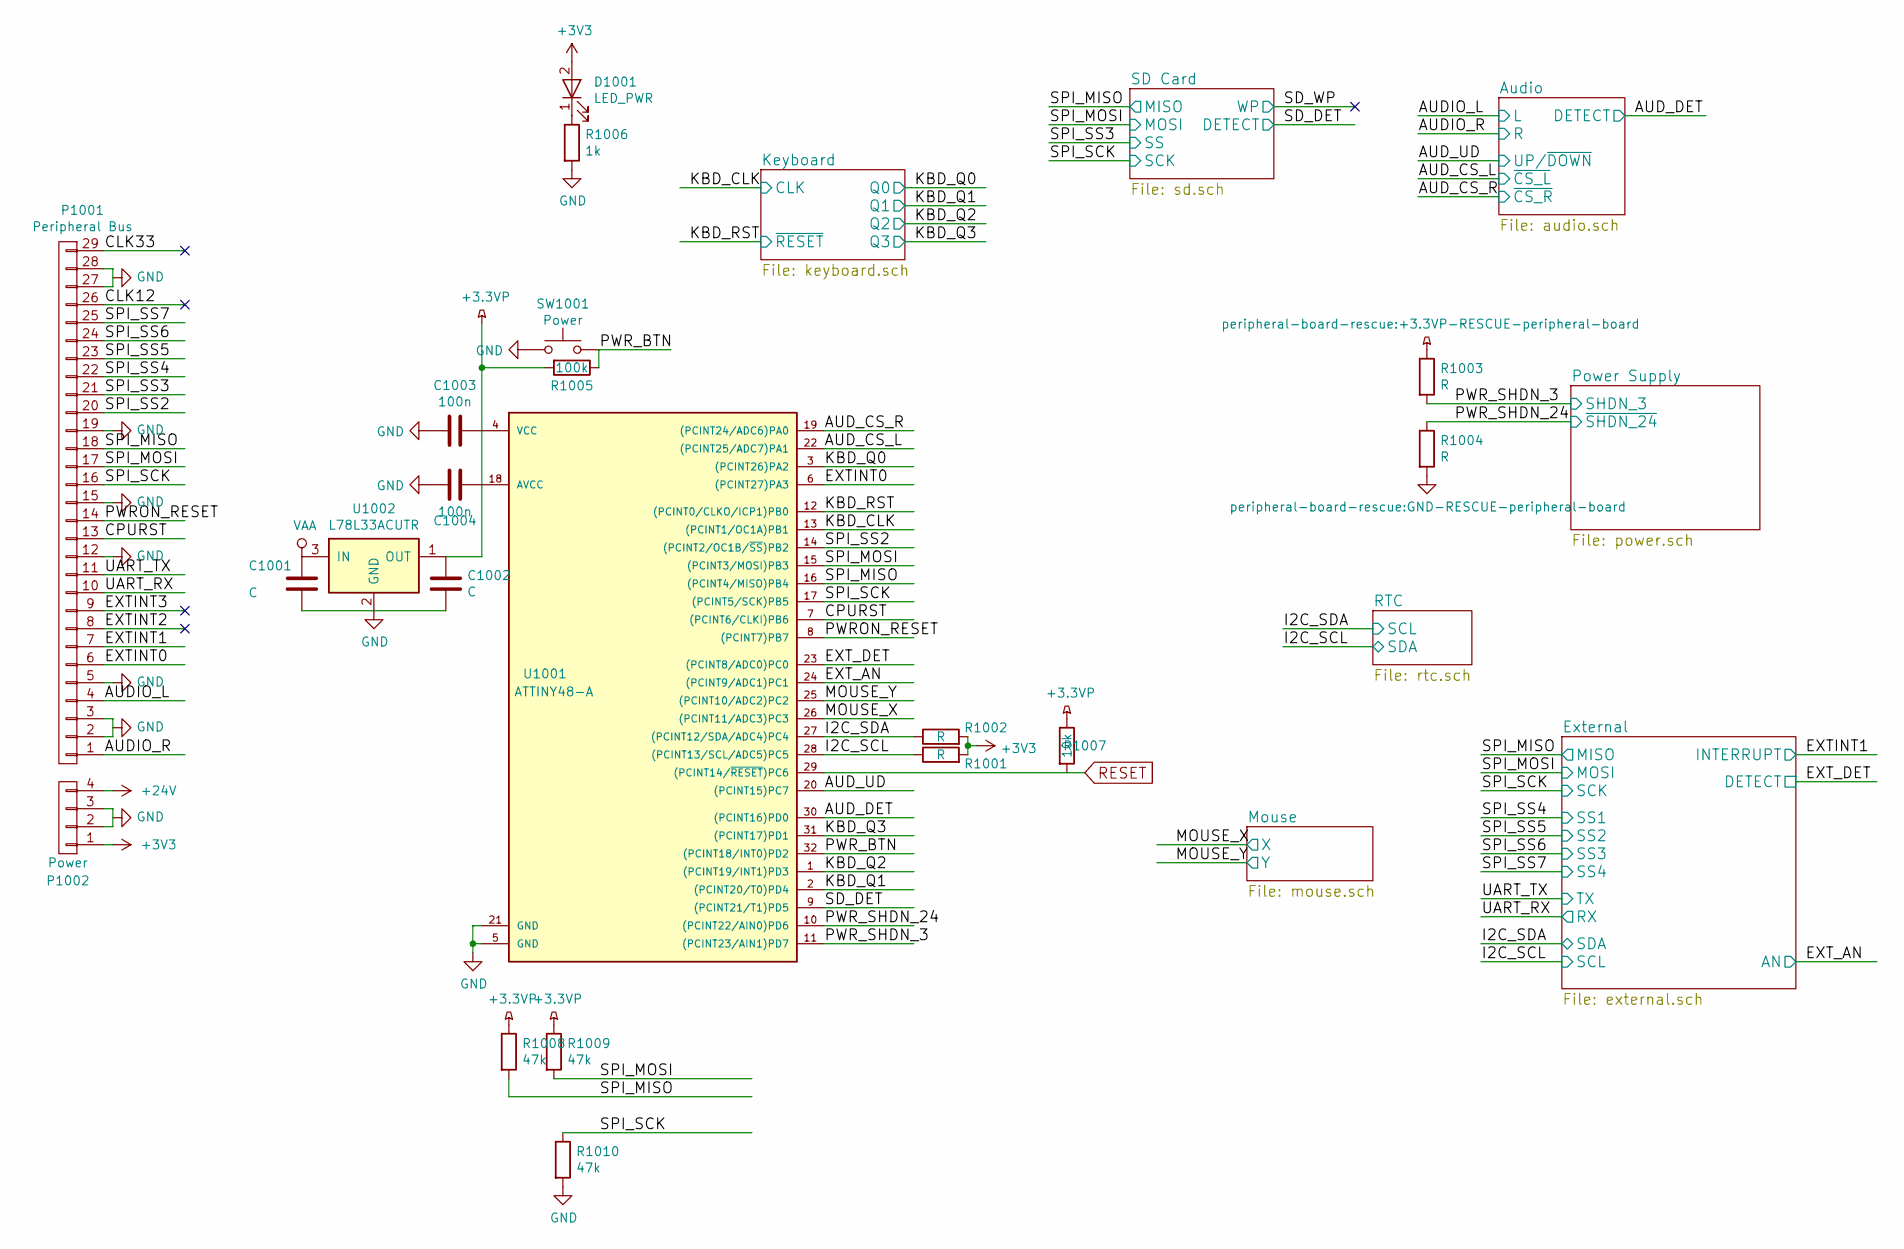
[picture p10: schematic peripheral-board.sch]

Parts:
C1001, C1002: C; C_0805
C1003, C1004: 100n; C_0805
D1001: LED_PWR; LED-3MM
P1001: Peripheral Bus; Socket_Strip_Straight_1x29
P1002: Power; Socket_Strip_Straight_1x04
R1001, R1002, R1003, R1004: R; R_0805
R1005: 100k; R_0805
R1006: 1k; R_0805
R1007: 10k; R_0805
R1008, R1009, R1010: 47k; R_0805
SW1001: Power; SMD-TACT-5.2x5.2x2mm
U1001: ATTINY48-A; TQFP-32_7x7mm_Pitch0.8mm
U1002: L78L33ACUTR; SOT89-3_Housing

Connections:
+3V3: D1001.2 (A), P1002.1, R1001.2, R1002.2; also elsewhere on the board
+24V: P1002.4; also elsewhere on the board
/AUDIO_L: P1001.4; also elsewhere on the board
/AUDIO_R: P1001.1; also elsewhere on the board
/AUD_CS_L: U1001.22 ((PCINT25/ADC7)PA1); also elsewhere on the board
/AUD_CS_R: U1001.19 ((PCINT24/ADC6)PA0); also elsewhere on the board
/AUD_DET: U1001.30 ((PCINT16)PD0); also elsewhere on the board
/AUD_UD: U1001.20 ((PCINT15)PC7); also elsewhere on the board
/CLK12: P1001.26
/CLK33: P1001.29
/CPURST: P1001.13, U1001.7 ((PCINT6/CLKI)PB6)
/EXTINT0: P1001.6, U1001.6 ((PCINT27)PA3)
/EXTINT1: P1001.7; also elsewhere on the board
/EXTINT2: P1001.8
/EXTINT3: P1001.9
/EXT_AN: U1001.24 ((PCINT9/ADC1)PC1); also elsewhere on the board
/EXT_DET: U1001.23 ((PCINT8/ADC0)PC0); also elsewhere on the board
/I2C_SCL: R1001.1, U1001.28 ((PCINT13/SCL/ADC5)PC5); also elsewhere on the board
/I2C_SDA: R1002.1, U1001.27 ((PCINT12/SDA/ADC4)PC4); also elsewhere on the board
/KBD_CLK: U1001.13 ((PCINT1/OC1A)PB1); also elsewhere on the board
/KBD_Q0: U1001.3 ((PCINT26)PA2); also elsewhere on the board
/KBD_Q1: U1001.2 ((PCINT20/T0)PD4); also elsewhere on the board
/KBD_Q2: U1001.1 ((PCINT19/INT1)PD3); also elsewhere on the board
/KBD_Q3: U1001.31 ((PCINT17)PD1); also elsewhere on the board
/KBD_RST: U1001.12 ((PCINT0/CLKO/ICP1)PB0); also elsewhere on the board
/MOUSE_X: U1001.26 ((PCINT11/ADC3)PC3); also elsewhere on the board
/MOUSE_Y: U1001.25 ((PCINT10/ADC2)PC2); also elsewhere on the board
/PWRON_RESET: P1001.14, U1001.8 ((PCINT7)PB7)
/PWR_BTN: R1005.1, SW1001.2, U1001.32 ((PCINT18/INT0)PD2)
/PWR_SHDN_3: R1003.2, U1001.11 ((PCINT23/AIN1)PD7); also elsewhere on the board
/PWR_SHDN_24: R1004.1, U1001.10 ((PCINT22/AIN0)PD6); also elsewhere on the board
/SD_DET: U1001.9 ((PCINT21/T1)PD5); also elsewhere on the board
/SPI_MISO: P1001.18, R1008.2, U1001.16 ((PCINT4/MISO)PB4); also elsewhere on the board
/SPI_MOSI: P1001.17, R1009.2, U1001.15 ((PCINT3/MOSI)PB3); also elsewhere on the board
/SPI_SCK: P1001.16, R1010.1, U1001.17 ((PCINT5/SCK)PB5); also elsewhere on the board
/SPI_SS2: P1001.20, U1001.14 ((PCINT2/OC1B/~SS~)PB2)
/SPI_SS3: P1001.21; also elsewhere on the board
/SPI_SS4: P1001.22; also elsewhere on the board
/SPI_SS5: P1001.23; also elsewhere on the board
/SPI_SS6: P1001.24; also elsewhere on the board
/SPI_SS7: P1001.25; also elsewhere on the board
/UART_RX: P1001.10; also elsewhere on the board
/UART_TX: P1001.11; also elsewhere on the board
unnamed: D1001.1 (K), R1006.1
RESET: R1007.2, U1001.29 ((PCINT14/~RESET~)PC6); also elsewhere on the board
VAA: C1001.1, U1002.3 (IN); also elsewhere on the board

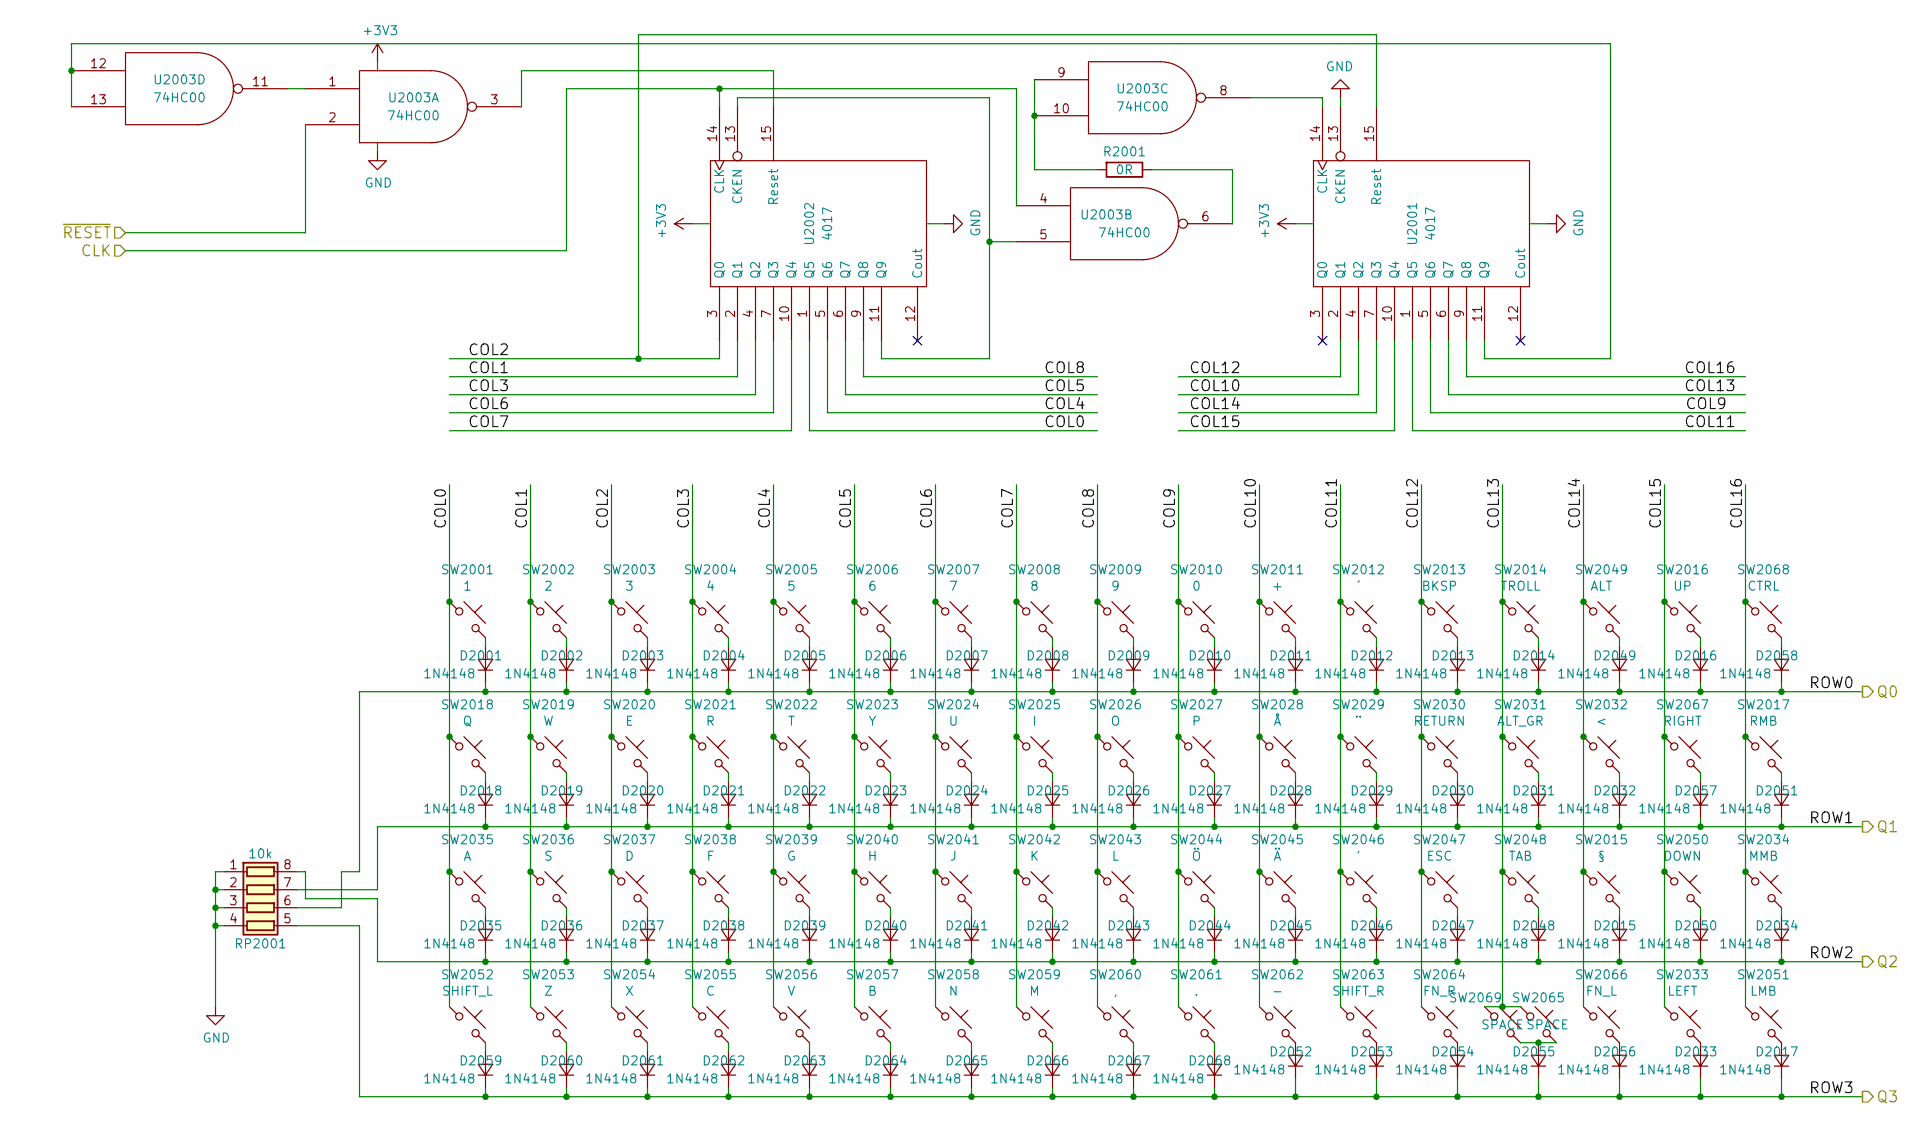
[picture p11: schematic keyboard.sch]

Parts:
D2001, D2002, D2003, D2004, D2005, D2006, D2007, D2008, D2009, D2010, D2011, D2012, D2013, D2014, D2015, D2016, D2017, D2018, D2019, D2020, D2021, D2022, D2023, D2024, D2025, D2026, D2027, D2028, D2029, D2030, D2031, D2032, D2033, D2034, D2035, D2036, D2037, D2038, D2039, D2040, D2041, D2042, D2043, D2044, D2045, D2046, D2047, D2048, D2049, D2050, D2051, D2052, D2053, D2054, D2055, D2056, D2057, D2058, D2059, D2060, D2061, D2062, D2063, D2064, D2065, D2066, D2067, D2068: 1N4148; D_MiniMELF_Standard
R2001: 0R; R_1206
RP2001: 10k; R_Cat16-4
SW2001: 1; SMD-TACT-5.2x5.2x2mm
SW2002: 2; SMD-TACT-5.2x5.2x2mm
SW2003: 3; SMD-TACT-5.2x5.2x2mm
SW2004: 4; SMD-TACT-5.2x5.2x2mm
SW2005: 5; SMD-TACT-5.2x5.2x2mm
SW2006: 6; SMD-TACT-5.2x5.2x2mm
SW2007: 7; SMD-TACT-5.2x5.2x2mm
SW2008: 8; SMD-TACT-5.2x5.2x2mm
SW2009: 9; SMD-TACT-5.2x5.2x2mm
SW2010: 0; SMD-TACT-5.2x5.2x2mm
SW2011: +; SMD-TACT-5.2x5.2x2mm
SW2012: ´; SMD-TACT-5.2x5.2x2mm
SW2013: BKSP; SMD-TACT-5.2x5.2x2mm
SW2014: TROLL; SMD-TACT-5.2x5.2x2mm
SW2015: §; SMD-TACT-5.2x5.2x2mm
SW2016: UP; SMD-TACT-5.2x5.2x2mm
SW2017: RMB; SMD-TACT-5.2x5.2x2mm
SW2018: Q; SMD-TACT-5.2x5.2x2mm
SW2019: W; SMD-TACT-5.2x5.2x2mm
SW2020: E; SMD-TACT-5.2x5.2x2mm
SW2021: R; SMD-TACT-5.2x5.2x2mm
SW2022: T; SMD-TACT-5.2x5.2x2mm
SW2023: Y; SMD-TACT-5.2x5.2x2mm
SW2024: U; SMD-TACT-5.2x5.2x2mm
SW2025: I; SMD-TACT-5.2x5.2x2mm
SW2026: O; SMD-TACT-5.2x5.2x2mm
SW2027: P; SMD-TACT-5.2x5.2x2mm
SW2028: Å; SMD-TACT-5.2x5.2x2mm
SW2029: ¨; SMD-TACT-5.2x5.2x2mm
SW2030: RETURN; SMD-TACT-5.2x5.2x2mm
SW2031: ALT_GR; SMD-TACT-5.2x5.2x2mm
SW2032: <; SMD-TACT-5.2x5.2x2mm
SW2033: LEFT; SMD-TACT-5.2x5.2x2mm
SW2034: MMB; SMD-TACT-5.2x5.2x2mm
SW2035: A; SMD-TACT-5.2x5.2x2mm
SW2036: S; SMD-TACT-5.2x5.2x2mm
SW2037: D; SMD-TACT-5.2x5.2x2mm
SW2038: F; SMD-TACT-5.2x5.2x2mm
SW2039: G; SMD-TACT-5.2x5.2x2mm
SW2040: H; SMD-TACT-5.2x5.2x2mm
SW2041: J; SMD-TACT-5.2x5.2x2mm
SW2042: K; SMD-TACT-5.2x5.2x2mm
SW2043: L; SMD-TACT-5.2x5.2x2mm
SW2044: Ö; SMD-TACT-5.2x5.2x2mm
SW2045: Ä; SMD-TACT-5.2x5.2x2mm
SW2046: '; SMD-TACT-5.2x5.2x2mm
SW2047: ESC; SMD-TACT-5.2x5.2x2mm
SW2048: TAB; SMD-TACT-5.2x5.2x2mm
SW2049: ALT; SMD-TACT-5.2x5.2x2mm
SW2050: DOWN; SMD-TACT-5.2x5.2x2mm
SW2051: LMB; SMD-TACT-5.2x5.2x2mm
SW2052: SHIFT_L; SMD-TACT-5.2x5.2x2mm
SW2053: Z; SMD-TACT-5.2x5.2x2mm
SW2054: X; SMD-TACT-5.2x5.2x2mm
SW2055: C; SMD-TACT-5.2x5.2x2mm
SW2056: V; SMD-TACT-5.2x5.2x2mm
SW2057: B; SMD-TACT-5.2x5.2x2mm
SW2058: N; SMD-TACT-5.2x5.2x2mm
SW2059: M; SMD-TACT-5.2x5.2x2mm
SW2060: ,; SMD-TACT-5.2x5.2x2mm
SW2061: .; SMD-TACT-5.2x5.2x2mm
SW2062: -; SMD-TACT-5.2x5.2x2mm
SW2063: SHIFT_R; SMD-TACT-5.2x5.2x2mm
SW2064: FN_R; SMD-TACT-5.2x5.2x2mm
SW2065, SW2069: SPACE; SMD-TACT-5.2x5.2x2mm
SW2066: FN_L; SMD-TACT-5.2x5.2x2mm
SW2067: RIGHT; SMD-TACT-5.2x5.2x2mm
SW2068: CTRL; SMD-TACT-5.2x5.2x2mm
U2001, U2002: 4017; SOIC-16_3.9x9.9mm_Pitch1.27mm
U2003: 74HC00; SOIC-14_3.9x8.7mm_Pitch1.27mm

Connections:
+3V3: U2001.16 (VDD), U2002.16 (VDD), U2003.14 (VCC); also elsewhere on the board
/KBD_CLK: U2002.14 (CLK), U2003.4; also elsewhere on the board
/KBD_Q0: D2001.1 (K), D2002.1 (K), D2003.1 (K), D2004.1 (K), D2005.1 (K), D2006.1 (K), D2007.1 (K), D2008.1 (K), D2009.1 (K), D2010.1 (K), D2011.1 (K), D2012.1 (K), D2013.1 (K), D2014.1 (K), D2016.1 (K), D2049.1 (K), D2058.1 (K), RP2001.6 (R3.2); also elsewhere on the board
/KBD_Q1: D2018.1 (K), D2019.1 (K), D2020.1 (K), D2021.1 (K), D2022.1 (K), D2023.1 (K), D2024.1 (K), D2025.1 (K), D2026.1 (K), D2027.1 (K), D2028.1 (K), D2029.1 (K), D2030.1 (K), D2031.1 (K), D2032.1 (K), D2051.1 (K), D2057.1 (K), RP2001.7 (R2.2); also elsewhere on the board
/KBD_Q2: D2015.1 (K), D2034.1 (K), D2035.1 (K), D2036.1 (K), D2037.1 (K), D2038.1 (K), D2039.1 (K), D2040.1 (K), D2041.1 (K), D2042.1 (K), D2043.1 (K), D2044.1 (K), D2045.1 (K), D2046.1 (K), D2047.1 (K), D2048.1 (K), D2050.1 (K), RP2001.8 (R1.2); also elsewhere on the board
/KBD_Q3: D2017.1 (K), D2033.1 (K), D2052.1 (K), D2053.1 (K), D2054.1 (K), D2055.1 (K), D2056.1 (K), D2059.1 (K), D2060.1 (K), D2061.1 (K), D2062.1 (K), D2063.1 (K), D2064.1 (K), D2065.1 (K), D2066.1 (K), D2067.1 (K), D2068.1 (K), RP2001.5 (R4.2); also elsewhere on the board
/KBD_RST: U2003.2; also elsewhere on the board
/Keyboard/COL0: SW2001.1, SW2018.1, SW2035.1, SW2052.1, U2002.1 (Q5)
/Keyboard/COL1: SW2002.1, SW2019.1, SW2036.1, SW2053.1, U2002.2 (Q1)
/Keyboard/COL2: SW2003.1, SW2020.1, SW2037.1, SW2054.1, U2001.15 (Reset), U2002.3 (Q0)
/Keyboard/COL3: SW2004.1, SW2021.1, SW2038.1, SW2055.1, U2002.4 (Q2)
/Keyboard/COL4: SW2005.1, SW2022.1, SW2039.1, SW2056.1, U2002.5 (Q6)
/Keyboard/COL5: SW2006.1, SW2023.1, SW2040.1, SW2057.1, U2002.6 (Q7)
/Keyboard/COL6: SW2007.1, SW2024.1, SW2041.1, SW2058.1, U2002.7 (Q3)
/Keyboard/COL7: SW2008.1, SW2025.1, SW2042.1, SW2059.1, U2002.10 (Q4)
/Keyboard/COL8: SW2009.1, SW2026.1, SW2043.1, SW2060.1, U2002.9 (Q8)
/Keyboard/COL9: SW2010.1, SW2027.1, SW2044.1, SW2061.1, U2001.5 (Q6)
/Keyboard/COL10: SW2011.1, SW2028.1, SW2045.1, SW2062.1, U2001.4 (Q2)
/Keyboard/COL11: SW2012.1, SW2029.1, SW2046.1, SW2063.1, U2001.1 (Q5)
/Keyboard/COL12: SW2013.1, SW2030.1, SW2047.1, SW2064.1, U2001.2 (Q1)
/Keyboard/COL13: SW2014.1, SW2031.1, SW2048.1, SW2065.1, SW2069.1, U2001.6 (Q7)
/Keyboard/COL14: SW2015.1, SW2032.1, SW2049.1, SW2066.1, U2001.7 (Q3)
/Keyboard/COL15: SW2016.1, SW2033.1, SW2050.1, SW2067.1, U2001.10 (Q4)
/Keyboard/COL16: SW2017.1, SW2034.1, SW2051.1, SW2068.1, U2001.9 (Q8)
unnamed: D2001.2 (A), SW2001.2
unnamed: D2002.2 (A), SW2002.2
unnamed: D2003.2 (A), SW2003.2
unnamed: D2004.2 (A), SW2004.2
unnamed: D2005.2 (A), SW2005.2
unnamed: D2006.2 (A), SW2006.2
unnamed: D2007.2 (A), SW2007.2
unnamed: D2008.2 (A), SW2008.2
unnamed: D2009.2 (A), SW2009.2
unnamed: D2010.2 (A), SW2010.2
unnamed: D2011.2 (A), SW2011.2
unnamed: D2012.2 (A), SW2012.2
unnamed: D2013.2 (A), SW2013.2
unnamed: D2014.2 (A), SW2014.2
unnamed: D2015.2 (A), SW2015.2
unnamed: D2016.2 (A), SW2016.2
unnamed: D2017.2 (A), SW2051.2
unnamed: D2018.2 (A), SW2018.2
unnamed: D2019.2 (A), SW2019.2
unnamed: D2020.2 (A), SW2020.2
unnamed: D2021.2 (A), SW2021.2
unnamed: D2022.2 (A), SW2022.2
unnamed: D2023.2 (A), SW2023.2
unnamed: D2024.2 (A), SW2024.2
unnamed: D2025.2 (A), SW2025.2
unnamed: D2026.2 (A), SW2026.2
unnamed: D2027.2 (A), SW2027.2
unnamed: D2028.2 (A), SW2028.2
unnamed: D2029.2 (A), SW2029.2
unnamed: D2030.2 (A), SW2030.2
unnamed: D2031.2 (A), SW2031.2
unnamed: D2032.2 (A), SW2032.2
unnamed: D2033.2 (A), SW2033.2
unnamed: D2034.2 (A), SW2034.2
unnamed: D2035.2 (A), SW2035.2
unnamed: D2036.2 (A), SW2036.2
unnamed: D2037.2 (A), SW2037.2
unnamed: D2038.2 (A), SW2038.2
unnamed: D2039.2 (A), SW2039.2
unnamed: D2040.2 (A), SW2040.2
unnamed: D2041.2 (A), SW2041.2
unnamed: D2042.2 (A), SW2042.2
unnamed: D2043.2 (A), SW2043.2
unnamed: D2044.2 (A), SW2044.2
unnamed: D2045.2 (A), SW2045.2
unnamed: D2046.2 (A), SW2046.2
unnamed: D2047.2 (A), SW2047.2
unnamed: D2048.2 (A), SW2048.2
unnamed: D2049.2 (A), SW2049.2
unnamed: D2050.2 (A), SW2050.2
unnamed: D2051.2 (A), SW2017.2
unnamed: D2052.2 (A), SW2062.2
unnamed: D2053.2 (A), SW2063.2
unnamed: D2054.2 (A), SW2064.2
unnamed: D2055.2 (A), SW2065.2, SW2069.2
unnamed: D2056.2 (A), SW2066.2
unnamed: D2057.2 (A), SW2067.2
unnamed: D2058.2 (A), SW2068.2
unnamed: D2059.2 (A), SW2052.2
unnamed: D2060.2 (A), SW2053.2
unnamed: D2061.2 (A), SW2054.2
unnamed: D2062.2 (A), SW2055.2
unnamed: D2063.2 (A), SW2056.2
unnamed: D2064.2 (A), SW2057.2
unnamed: D2065.2 (A), SW2058.2
unnamed: D2066.2 (A), SW2059.2
unnamed: D2067.2 (A), SW2060.2
unnamed: D2068.2 (A), SW2061.2
unnamed: R2001.1, U2003.6
unnamed: R2001.2, U2003.9, U2003.10
unnamed: U2001.11 (Q9), U2003.12, U2003.13
unnamed: U2001.14 (CLK), U2003.8
unnamed: U2002.11 (Q9), U2002.13 (CKEN), U2003.5
unnamed: U2002.15 (Reset), U2003.3
unnamed: U2003.1, U2003.11

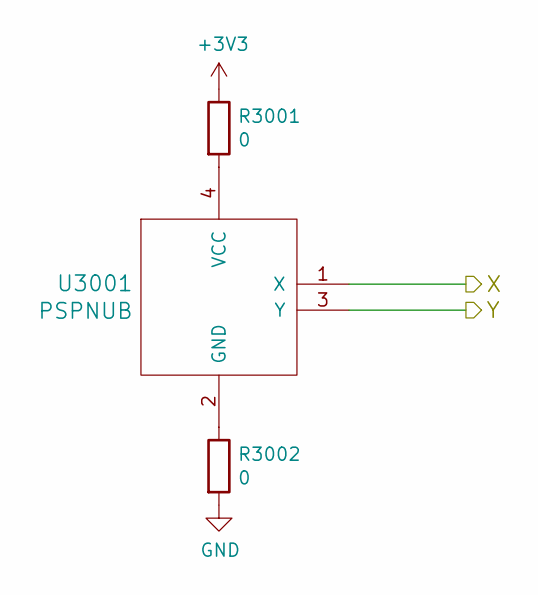
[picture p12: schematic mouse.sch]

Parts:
R3001, R3002: 0; R_1206
U3001: PSPNUB

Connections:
+3V3: R3001.1; also elsewhere on the board
/MOUSE_X: U3001.1 (X); also elsewhere on the board
/MOUSE_Y: U3001.3 (Y); also elsewhere on the board
unnamed: R3001.2, U3001.4 (VCC)
unnamed: R3002.1, U3001.2 (GND)

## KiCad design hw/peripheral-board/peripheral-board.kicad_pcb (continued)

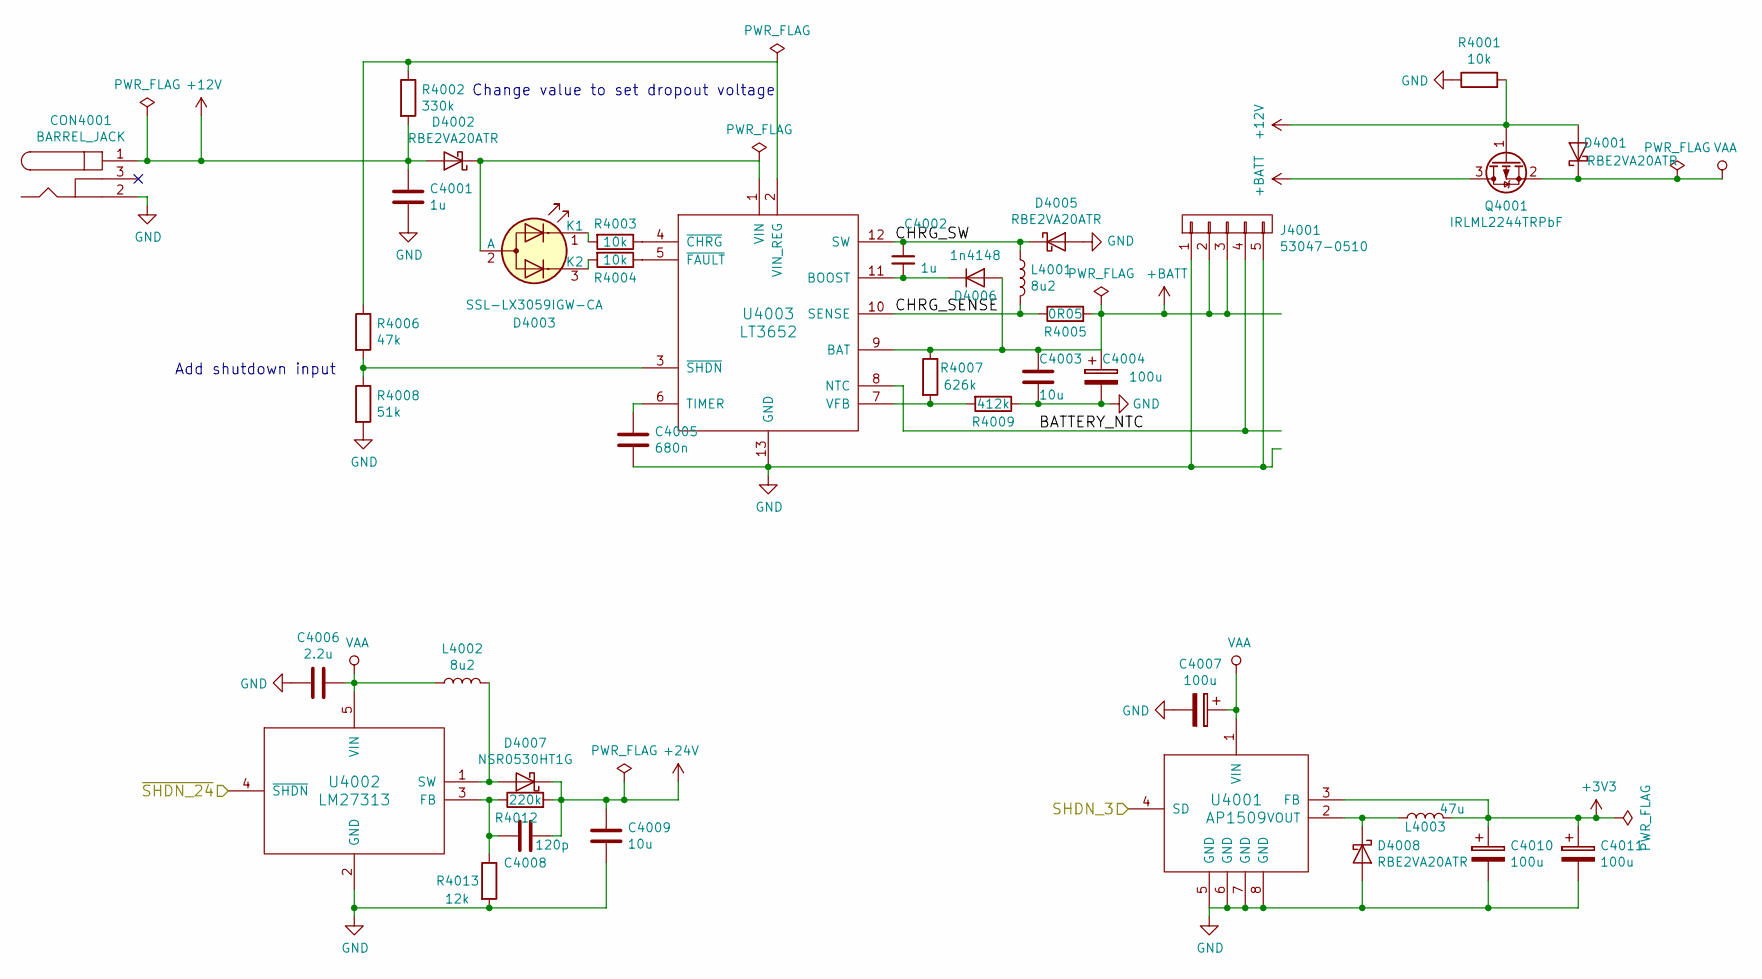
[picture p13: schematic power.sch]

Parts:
C4001, C4002: 1u; C_1206
C4003, C4009: 10u; C_1206
C4004, C4007: 100u; TantalC_SizeD_EIA-7343_Reflow
C4005: 680n; C_0805
C4006: 2.2u; C_1206
C4008: 120p; C_0805
C4010, C4011: 100u; c_elec_6.3x5.8
CON4001: BARREL_JACK; JACK_ALIM
D4001, D4002, D4005, D4008: RBE2VA20ATR; D_TUMD2
D4003: SSL-LX3059IGW-CA; LED-5MM-3
D4006: 1n4148; D_MiniMELF_Standard
D4007: NSR0530HT1G; D_SOD-323
J4001: 53047-0510; Connector_Molex_PicoBlade_53047-0510
L4001, L4002: 8u2; Choke_SMD_6.3x6.3_H3
L4003: 47u; Choke_SMD_12x12mm_h6mm
Q4001: IRLML2244TRPbF; SOT-23
R4001, R4003, R4004: 10k; R_0805
R4002: 330k; R_0805
R4005: 0R05; R_1812
R4006: 47k; R_0805
R4007: 626k; R_0805
R4008: 51k; R_0805
R4009: 412k; R_0805
R4012: 220k; R_0805
R4013: 12k; R_0805
U4001: AP1509; SOIC-8_3.9x4.9mm_Pitch1.27mm
U4002: LM27313; SOT-23-5
U4003: LT3652; MSOP-12-1EP_3x4mm_Pitch0.65mm

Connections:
+3V3: C4010.1, C4011.1, L4003.2, U4001.3 (FB); also elsewhere on the board
+12V: C4001.1, CON4001.1, D4001.2 (A), D4002.2 (A), Q4001.1 (G), R4001.2, R4002.2
+24V: C4008.1, C4009.1, D4007.1 (K), R4012.2; also elsewhere on the board
+BATT: C4003.1, C4004.1, D4006.2 (A), J4001.2, J4001.3, Q4001.3 (D), R4005.2, R4007.1, U4003.9 (BAT)
/PWR_SHDN_3: U4001.4 (SD); also elsewhere on the board
/PWR_SHDN_24: U4002.4 (~SHDN); also elsewhere on the board
/Power Supply/BATTERY_NTC: J4001.4, U4003.8 (NTC)
/Power Supply/CHRG_SENSE: L4001.2, R4005.1, U4003.10 (SENSE)
/Power Supply/CHRG_SW: C4002.1, D4005.1 (K), L4001.1, U4003.12 (SW)
unnamed: C4002.2, D4006.1 (K), U4003.11 (BOOST)
unnamed: C4005.1, U4003.6 (TIMER)
unnamed: C4008.2, R4012.1, R4013.1, U4002.3 (FB)
unnamed: D4002.1 (K), D4003.2 (A), U4003.1 (VIN)
unnamed: D4003.1 (K1), R4003.2
unnamed: D4003.3 (K2), R4004.2
unnamed: D4007.2 (A), L4002.2, U4002.1 (SW)
unnamed: D4008.1 (K), L4003.1, U4001.2 (VOUT)
unnamed: R4002.1, R4006.1, U4003.2 (VIN_REG)
unnamed: R4003.1, U4003.4 (~CHRG)
unnamed: R4004.1, U4003.5 (~FAULT)
unnamed: R4006.2, R4008.1, U4003.3 (~SHDN)
unnamed: R4007.2, R4009.2, U4003.7 (VFB)
VAA: C4006.1, C4007.1, D4001.1 (K), L4002.1, Q4001.2 (S), U4001.1 (VIN), U4002.5 (VIN); also elsewhere on the board

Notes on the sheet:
Change value to set dropout voltage
Add shutdown input

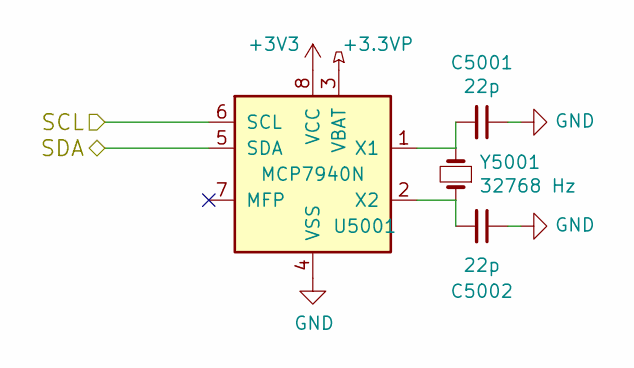
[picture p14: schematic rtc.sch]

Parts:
C5001, C5002: 22p; C_0603
U5001: MCP7940N; SOIC-8_3.9x4.9mm_Pitch1.27mm
Y5001: 32768 Hz; Crystal_Watch

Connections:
+3V3: U5001.8 (VCC); also elsewhere on the board
/I2C_SCL: U5001.5 (SDA); also elsewhere on the board
/I2C_SDA: U5001.6 (SCL); also elsewhere on the board
unnamed: C5001.2, U5001.1 (X1), Y5001.2
unnamed: C5002.2, U5001.2 (X2), Y5001.1

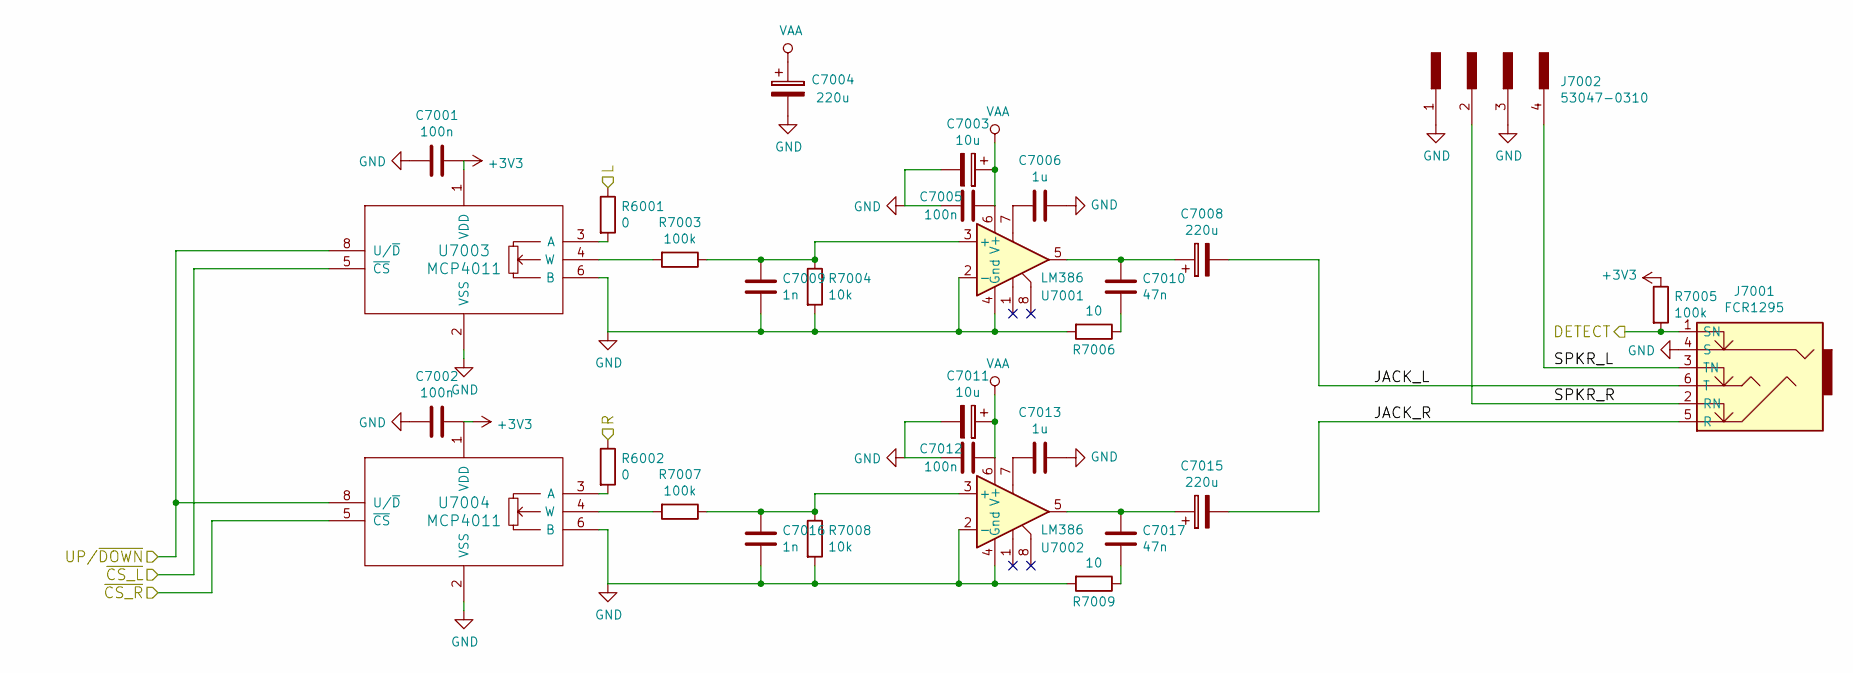
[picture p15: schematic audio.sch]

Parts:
C7001, C7002, C7005, C7012: 100n; C_0805
C7003, C7011: 10u; c_elec_6.3x5.8
C7004, C7008, C7015: 220u; c_elec_8x6.7
C7006, C7013: 1u; C_0805
C7009, C7016: 1n; C_0805
C7010, C7017: 47n; C_0805
J7001: FCR1295
J7002: 53047-0310; Connector_Molex_PicoBlade_53047-0410
R6001, R6002: 0; R_1206
R7003, R7005, R7007: 100k; R_0805
R7004, R7008: 10k; R_0805
R7006, R7009: 10; R_0805
U7001, U7002: LM386; SOIC-8_3.9x4.9mm_Pitch1.27mm
U7003, U7004: MCP4011; SOIC-8_3.9x4.9mm_Pitch1.27mm

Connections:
+3V3: C7001.1, C7002.1, R7005.1, U7003.1 (VDD), U7004.1 (VDD); also elsewhere on the board
/AUDIO_L: R6001.1; also elsewhere on the board
/AUDIO_R: R6002.1; also elsewhere on the board
/AUD_CS_L: U7003.5 (~CS); also elsewhere on the board
/AUD_CS_R: U7004.5 (~CS); also elsewhere on the board
/AUD_DET: J7001.1 (SN), R7005.2; also elsewhere on the board
/AUD_UD: U7003.8 (U/~D), U7004.8 (U/~D); also elsewhere on the board
/Audio/JACK_L: C7008.2, J7001.6 (T)
/Audio/JACK_R: C7015.2, J7001.5 (R)
/Audio/SPKR_L: J7001.3 (TN), J7002.4
/Audio/SPKR_R: J7001.2 (RN), J7002.2
unnamed: C7006.2, U7001.7
unnamed: C7008.1, C7010.1, U7001.5
unnamed: C7009.1, R7003.1, R7004.1, U7001.3 (+)
unnamed: C7010.2, R7006.1
unnamed: C7013.2, U7002.7
unnamed: C7015.1, C7017.1, U7002.5
unnamed: C7016.1, R7007.1, R7008.1, U7002.3 (+)
unnamed: C7017.2, R7009.1
unnamed: R6001.2, U7003.3 (A)
unnamed: R6002.2, U7004.3 (A)
unnamed: R7003.2, U7003.4 (W)
unnamed: R7007.2, U7004.4 (W)
VAA: C7003.1, C7004.1, C7005.1, C7011.1, C7012.1, U7001.6 (V+), U7002.6 (V+); also elsewhere on the board

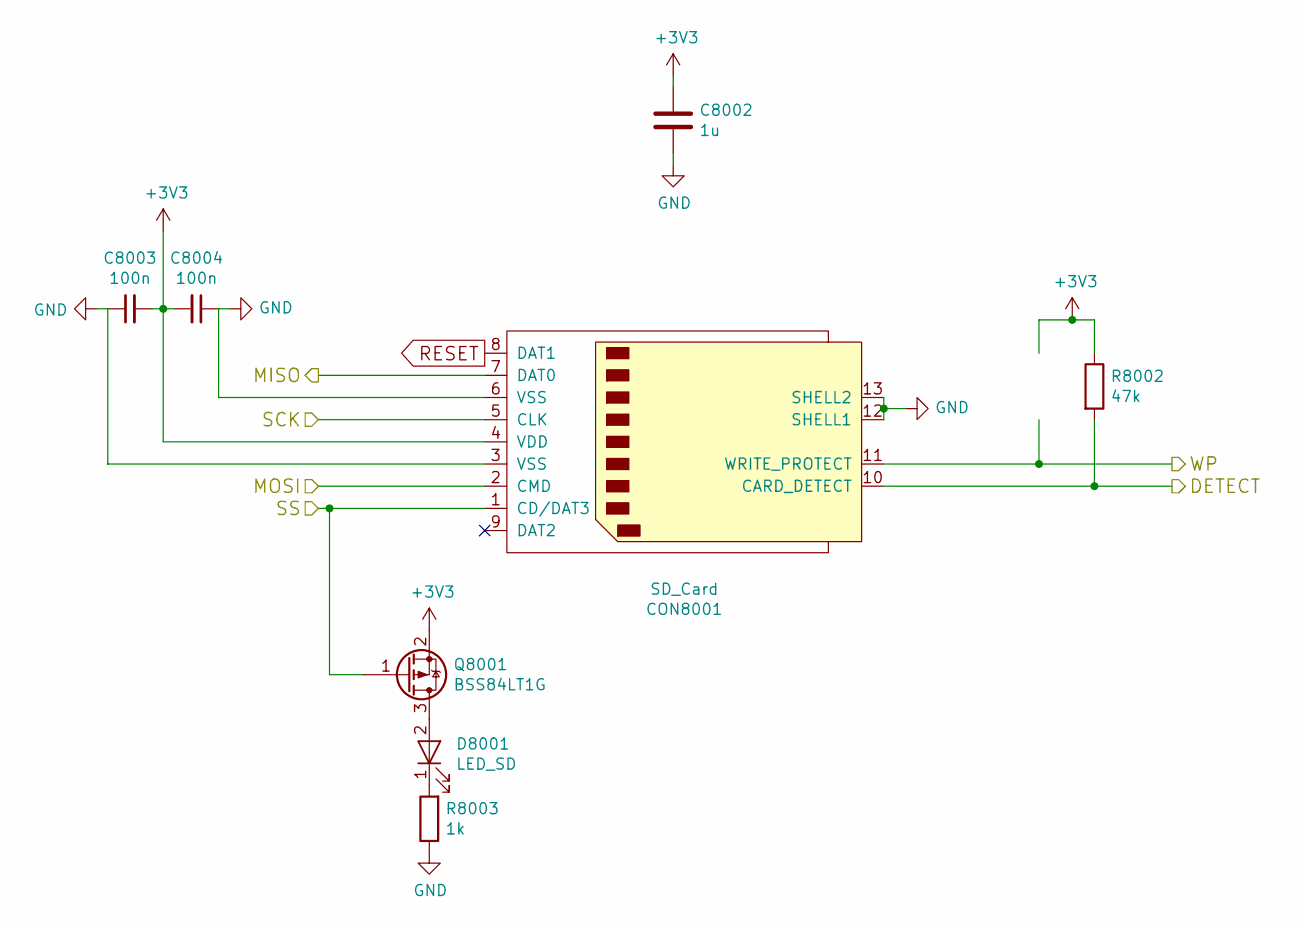
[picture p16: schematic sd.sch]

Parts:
C8002: 1u; C_0805
C8003, C8004: 100n; C_0805
CON8001: SD_Card; TS-2198-01
D8001: LED_SD; LED-3MM
Q8001: BSS84LT1G; SOT-23
R8002: 47k; R_0805
R8003: 1k; R_0805

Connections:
+3V3: C8002.1, C8003.2, C8004.2, CON8001.4 (VDD), Q8001.2 (S), R8002.1; also elsewhere on the board
/SD_DET: CON8001.10 (CARD_DETECT), R8002.2; also elsewhere on the board
/SD_WP: CON8001.11 (WRITE_PROTECT)
/SPI_MISO: CON8001.7 (DAT0); also elsewhere on the board
/SPI_MOSI: CON8001.2 (CMD); also elsewhere on the board
/SPI_SCK: CON8001.5 (CLK); also elsewhere on the board
/SPI_SS3: CON8001.1 (CD/DAT3), Q8001.1 (G); also elsewhere on the board
unnamed: D8001.1 (K), R8003.2
unnamed: D8001.2 (A), Q8001.3 (D)
RESET: CON8001.8 (DAT1); also elsewhere on the board

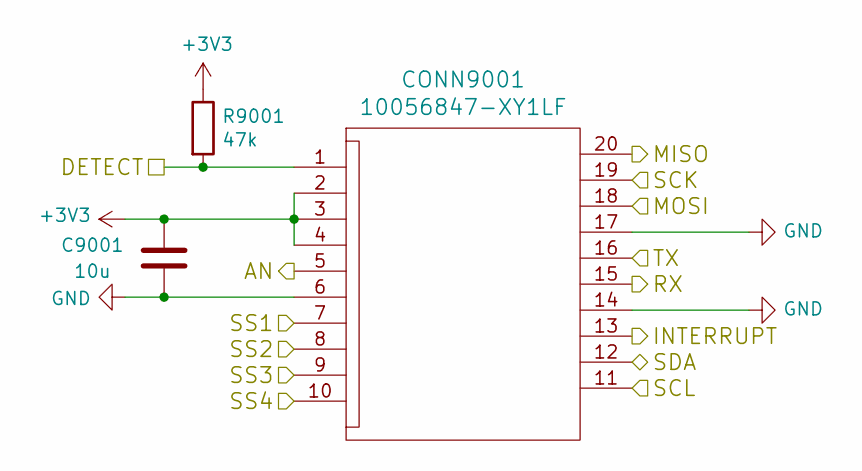
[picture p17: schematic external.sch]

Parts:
C9001: 10u; C_1206
CONN9001: 10056847-XY1LF
R9001: 47k; R_0805

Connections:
+3V3: C9001.1, CONN9001.2, CONN9001.3, CONN9001.4, R9001.1; also elsewhere on the board
/EXTINT1: CONN9001.13; also elsewhere on the board
/EXT_AN: CONN9001.5; also elsewhere on the board
/EXT_DET: CONN9001.1, R9001.2; also elsewhere on the board
/I2C_SCL: CONN9001.11; also elsewhere on the board
/I2C_SDA: CONN9001.12; also elsewhere on the board
/SPI_MISO: CONN9001.20; also elsewhere on the board
/SPI_MOSI: CONN9001.18; also elsewhere on the board
/SPI_SCK: CONN9001.19; also elsewhere on the board
/SPI_SS4: CONN9001.7; also elsewhere on the board
/SPI_SS5: CONN9001.8; also elsewhere on the board
/SPI_SS6: CONN9001.9; also elsewhere on the board
/SPI_SS7: CONN9001.10; also elsewhere on the board
/UART_RX: CONN9001.15; also elsewhere on the board
/UART_TX: CONN9001.16; also elsewhere on the board

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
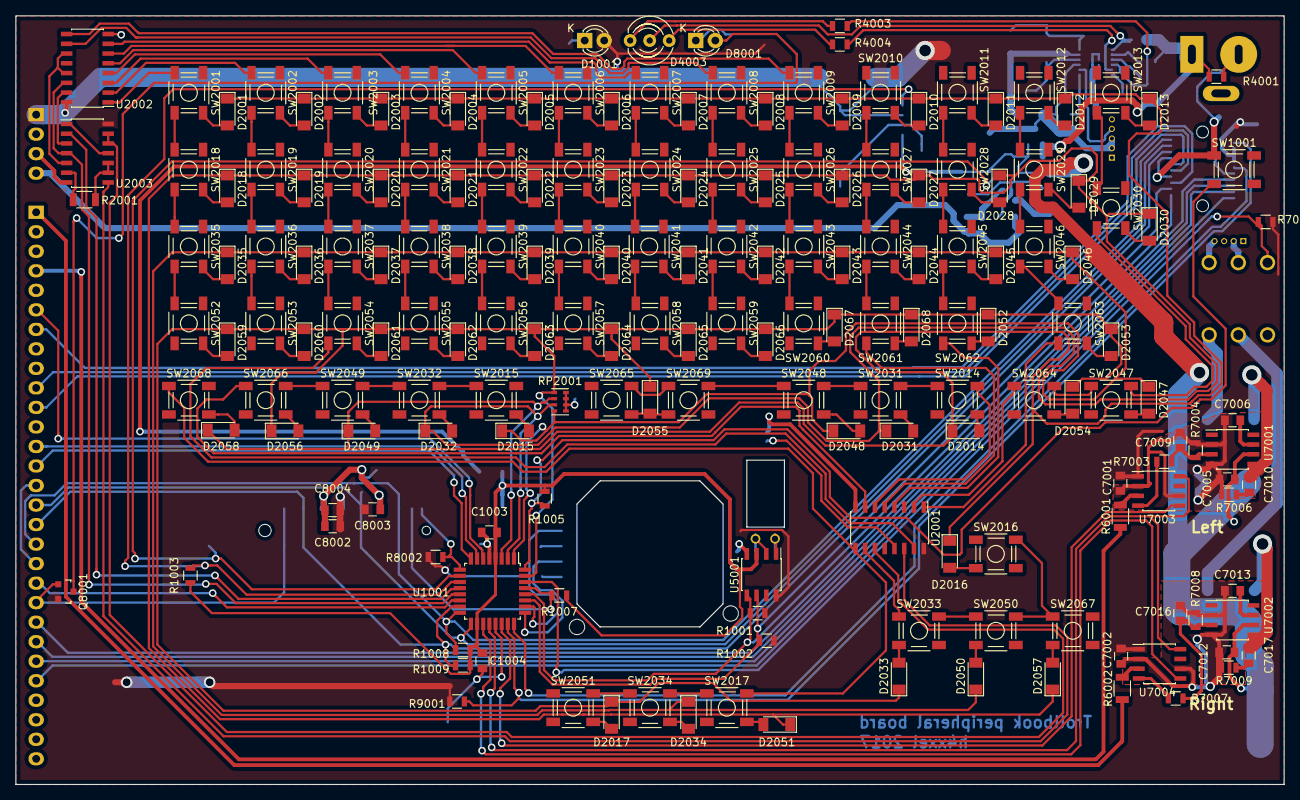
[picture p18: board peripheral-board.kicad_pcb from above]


Board: 2 copper layers, 165.0 x 100.0 mm, 248 parts (59 on the bottom side), 176 nets.

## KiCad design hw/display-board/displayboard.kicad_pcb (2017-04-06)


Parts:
J1001: CONN_01X04; Socket_Strip_Straight_1x04_Pitch2.54mm
LS1001: L Speaker; CP_Radial_D10.0mm_P7.50mm
LS1002: R Speaker; CP_Radial_D10.0mm_P7.50mm
P1001, P1002: ER-CON40HT-1

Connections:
GND: J1001.2, J1001.4, LS1001.2, LS1002.2, P1001.GND, P1002.GND
unnamed: J1001.1, LS1001.1
unnamed: J1001.3, LS1002.1
unnamed: P1001.1, P1002.1
unnamed: P1001.2, P1002.2
unnamed: P1001.3, P1002.3
unnamed: P1001.4, P1002.4
unnamed: P1001.5, P1002.5
unnamed: P1001.6, P1002.6
unnamed: P1001.7, P1002.7
unnamed: P1001.8, P1002.8
unnamed: P1001.9, P1002.9
unnamed: P1001.10, P1002.10
unnamed: P1001.11, P1002.11
unnamed: P1001.12, P1002.12
unnamed: P1001.13, P1002.13
unnamed: P1001.14, P1002.14
unnamed: P1001.15, P1002.15
unnamed: P1001.16, P1002.16
unnamed: P1001.17, P1002.17
unnamed: P1001.18, P1002.18
unnamed: P1001.19, P1002.19
unnamed: P1001.20, P1002.20
unnamed: P1001.21, P1002.21
unnamed: P1001.22, P1002.22
unnamed: P1001.23, P1002.23
unnamed: P1001.24, P1002.24
unnamed: P1001.25, P1002.25
unnamed: P1001.26, P1002.26
unnamed: P1001.27, P1002.27
unnamed: P1001.28, P1002.28
unnamed: P1001.29, P1002.29
unnamed: P1001.30, P1002.30
unnamed: P1001.31, P1002.31
unnamed: P1001.32, P1002.32
unnamed: P1001.33, P1002.33
unnamed: P1001.34, P1002.34
unnamed: P1001.35, P1002.35
unnamed: P1001.36, P1002.36
unnamed: P1001.37, P1002.37
unnamed: P1001.38, P1002.38
unnamed: P1001.39, P1002.39
unnamed: P1001.40, P1002.40



Board: 2 copper layers, 170.0 x 114.0 mm, 5 parts (2 on the bottom side), 43 nets.

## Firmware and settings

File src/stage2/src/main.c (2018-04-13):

#include <stdint.h>
#include <stdbool.h>
#include <stddef.h>
#include "uart.h"
#include "spi.h"
#include "printf.h"
#include "terminal.h"
#include "menu.h"
#include "sd.h"
#include "input.h"
#include "hexload.h"
#include "rom.h"
#include "fat.h"
#include "cache.h"
#include "filebrowse.h"
#include "memtest.h"
#include "serial-transfer.h"
#include "main.h"

static void clear_and_print(void *arg);
static void test_spi_rom(void *arg);
static void test_sdram(void *arg);
static void test_lowres(void *arg);
static void autoboot(void *arg);
void color_demo(void *arg);
static void test_sound(void *arg);

uint8_t fat_buf[512];

static const char *sd_card_type_name[] = {
	[SD_CARD_TYPE_MMC] = "MMC",
	[SD_CARD_TYPE_SD] = "SD",
	[SD_CARD_TYPE_SDHC] = "SDHC",
};

static const char *fat_type_name[] = {
	[FAT_TYPE_FAT16] = "FAT16",
	[FAT_TYPE_FAT32] = "FAT32",
};

Menu menu_main = {
	clear_and_print,
	"Trollectronics Trollbook BIOS\nMain menu\n----------------------------------------\n",
	false,
	0,
	9,
	{
		{"Boot kernel.elf", autoboot, (void *) false},
		{"Debug kernel.elf", autoboot, (void *) true},
		{"Browse SD card filesystem", menu_execute, &menu_dir},
		{"Serial file transfer to SD", serial_transfer_recv, NULL},
		{"Test SPI ROM", test_spi_rom, NULL},
		{"Test input", input_test_keyboard, NULL},
		{"Test Low-res video mode", test_lowres, NULL},
		{"SDRAM Memtest", test_sdram, NULL},
		{"Reboot", reboot, NULL},
	},
};


static int fat_read_sd(uint32_t sector, uint8_t *data) {
	SDStreamStatus status;
	
	status = SD_STREAM_STATUS_BEGIN;
	
	sd_stream_read_block(&status, sector);
	if(status == SD_STREAM_STATUS_FAILED)
		return -1;
	
	while(status >= 1)
		*data++ = sd_stream_read_block(&status);
	
	if(status == SD_STREAM_STATUS_FAILED)
		return -1;
	
	return 0;
}

static int fat_write_sd(uint32_t sector, uint8_t *data) {
	SDStreamStatus status;
	
	status = SD_STREAM_STATUS_BEGIN;
	
	sd_stream_write_block(&status, sector);
	if(status == SD_STREAM_STATUS_FAILED)
		return -1;
	
	while(status >= 1)
		sd_stream_write_block(&status, *data++);
	
	if(status == SD_STREAM_STATUS_FAILED)
		return -1;
	
	return 0;
}

static void print_filesize(uint32_t filesize) {
	if(filesize < 1024)
		printf("%u", filesize);
	else if(filesize < 1024*1024)
		printf("%uk", filesize/1024U);
	else
		printf("%uM", filesize/(1024U*1024U));
}

static void clear_and_print(void *arg) {
	static bool clear = false;
	
	if(clear)
		terminal_clear();
	
	clear = true;
	printf("%s", arg);
}

static void test_spi_rom(void *arg) {
	uint8_t buf[256];
	uint8_t *tmp;
	int i, j, k;
	
	for(j = 0x5DD00; ; j += 256) {
		terminal_clear();
		rom_read(j, buf, 256);
		for(i = 0; i < 256; i+=16) {
			tmp =((uint8_t *) buf) + i;
			printf("%04x\t%02x %02x %02x %02x %02x %02x %02x %02x %02x %02x %02x %02x %02x %02x %02x %02x\t\t", 
				j + i,
				tmp[0], tmp[1], tmp[2], tmp[3], tmp[4], tmp[5], tmp[6], tmp[7], 
				tmp[8], tmp[9], tmp[10], tmp[11], tmp[12], tmp[13], tmp[14], tmp[15]
			);
			for(k = 0; k < 16; k++) {
				if(tmp[k] < 32 || tmp[k] > 126)
					printf("%c", '.');
				else
					printf("%c", tmp[k]);
			}
			printf("\n");
		}
		
		input_poll();
	}
}

static void test_sdram(void *arg) {
	terminal_clear();
	
	printf("Performing memtest without the cache\n");
	memtest_run(false);
	printf("Performing memtest with the cache\n");
	memtest_run(true);
	
	input_poll();
}

void color_demo(void *arg) {
	unsigned int i, col = 0;
	for(;;) {
		for(i = 0; i < 230; i++) {
			terminal_set_fg(col++);
			terminal_puts("Hello, world ");
		}
		terminal_set_fg(col++);
		terminal_puts("Hello, wor");
		terminal_set_pos(0, 0);
	}
}

static void autoboot(void *arg) {
	bool debug = (bool) arg;
	execute_elf_path("/KERNEL.ELF", debug);
}

static void test_sound(void *arg) {
	volatile uint16_t *buf= (volatile uint16_t *) LLRAM_BASE;
	volatile uint32_t *sound_hw = (volatile uint32_t *) PERIPHERAL_SOUND_BASE;
	int buffer;
	unsigned int i;
	
	for(i = 0; i < 1024; i++) {
		buf[i] = 0;
	}
	
	sound_hw[2] = 0x0;
	sound_hw[3] = 3;
	sound_hw[4] = 512;
	buffer = sound_hw[1] & 0x1;
	sound_hw[0] = 0x1;
	
	for(;;) {
		sound_wait();
		for(i = 0; i < 256; i++) {
			buf[i] = 0xFFFF;
		}
		sound_wait();
		for(i = 512; i < 768; i++) {
			buf[i] = 0xFFFF;
		}
		sound_wait();
		for(i = 0; i < 256; i++) {
			buf[i] = 0x0;
		}
		sound_wait();
		for(i = 512; i < 768; i++) {
			buf[i] = 0x0;
		}
	}
}

static void test_lowres(void *arg) {
	volatile uint8_t *buf= (volatile uint8_t *) LLRAM_BASE;
	volatile uint32_t *vga_hw = (volatile uint32_t *) PERIPHERAL_VGA_BASE;
	int i;
	
	//~ for(i = 0; i < 400*240/2; i++) {
		//~ buf[i] = 0x1;
		//~ buf[i + 400] = 0x2;
	//~ }
	
	//~ for(i = 0; i < 400*240/2; i++) {
		//~ buf[i + 128*1024] = 0x4;
		//~ buf[i + 400 + 128*1024] = 0x5;
	//~ }
	
	input_poll();
	
	vga_hw[0] = 0x3;
	input_poll();
	vga_hw[0] = 0x7;
	input_poll();
	
	vga_hw[0] = 0x1;
}

int main() {
	int type;
	char label[12];
	
	terminal_init();
	
	printf("Detecting SD card: ");
	if((type = sd_init()) == SD_CARD_TYPE_INVALID) {
		goto fail;
	}
	
	terminal_set_fg(TERMINAL_COLOR_LIGHT_GREEN);
	printf("%s\n", sd_card_type_name[type]);
	terminal_set_fg(TERMINAL_COLOR_WHITE);
	printf(" - Card size: ");
	print_filesize(sd_get_card_size()/2*1024);
	printf("B\n");
	
	printf("Detecting file system: ");
	if(fat_init(fat_read_sd, fat_write_sd, fat_buf) < 0) {
		goto fail;
	}
	
	type = fat_type();
	terminal_set_fg(TERMINAL_COLOR_LIGHT_GREEN);
	printf("%s\n", fat_type_name[type]);
	terminal_set_fg(TERMINAL_COLOR_WHITE);
	fat_get_label(label);
	printf(" - Volume label: %s\n\n", label);
	
	menu_execute(&menu_main);
	
	for(;;);
	
	fail:
	terminal_set_fg(TERMINAL_COLOR_LIGHT_RED);
	printf("failed");
	terminal_set_fg(TERMINAL_COLOR_WHITE);
	
	for(;;);
		
	return 0;
}

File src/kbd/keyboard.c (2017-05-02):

#include <stdint.h>
#include <stdbool.h>
#include <string.h>
#include <avr/io.h>
#include "protocol.h"
#include "interrupt.h"

#define KBD_RESET_DEASSERT() (PORTB |= (1 << 0))
#define KBD_RESET_ASSERT() (PORTB &= ~(1 << 0))

#define KBD_CLK_ASSERT() (PORTB |= (1 << 1))
#define KBD_CLK_DEASSERT() (PORTB &= ~(1 << 1))

#define KBD_Q0 ((PINA >> 2) & 1)
#define KBD_Q1 ((PIND >> 4) & 1)
#define KBD_Q2 ((PIND >> 3) & 1)
#define KBD_Q3 ((PIND >> 1) & 1)

#define COLUMNS 17

typedef enum KeyboardState KeyboardState;
enum KeyboardState {
	KEYBOARD_STATE_RESET,
	KEYBOARD_STATE_CLK_LOW,
	KEYBOARD_STATE_CLK_HIGH,
};

struct {
	uint8_t keystate[9];
	uint8_t column;
	KeyboardState state;
	uint8_t event[8];
	uint8_t event_first;
	uint8_t event_last;
} keyboard;

uint8_t keyboard_init() {
	uint8_t row;
	DDRB |= (1 << 0); //KBD_RESET output
	DDRB |= (1 << 1); //KBD_CLK output
	DDRA &= ~(1 << 2); //KBD_Q0 input
	DDRD &= ~(1 << 4); //KBD_Q1 input
	DDRD &= ~(1 << 3); //KBD_Q2 input
	DDRD &= ~(1 << 1); //KBD_Q3 input
	KBD_CLK_DEASSERT();
	KBD_RESET_ASSERT();
	
	memset(&keyboard, 0, sizeof(keyboard));
	row = KBD_Q0 | (KBD_Q1 << 1) | (KBD_Q2 << 2) | (KBD_Q3 << 3);
	
	return row;
}

void keyboard_deinit() {
	DDRB &= ~(1 << 0); //KBD_RESET input
	DDRB &= ~(1 << 1); //KBD_CLK input
	DDRA &= ~(1 << 2); //KBD_Q0 input
	DDRD &= ~(1 << 4); //KBD_Q1 input
	DDRD &= ~(1 << 3); //KBD_Q2 input
	DDRD &= ~(1 << 1); //KBD_Q3 input
}

void keyboard_event_push(uint8_t ev) {
	uint8_t last;
	reg_status.keyboard_if = true;
	
	last = keyboard.event_last;
	keyboard.event[keyboard.event_last++] = ev;
	if(keyboard.event_last == 8)
		keyboard.event_last = 0;
	
	if(keyboard.event_last == keyboard.event_first)
		keyboard.event_last = last;
}

int16_t keyboard_event_pop() {
	uint8_t ret;
	
	if(keyboard.event_first == keyboard.event_last) {
		reg_status.keyboard_if = false;
		return -1;
	}
	
	ret = keyboard.event[keyboard.event_first++];
	if(keyboard.event_first == 8)
		keyboard.event_first = 0;
	
	if(keyboard.event_first == keyboard.event_last)
		reg_status.keyboard_if = false;
	
	return ret;
}

void keyboard_tick() {
	uint8_t row;
	uint8_t oldrow;
	uint8_t i;
	
	switch(keyboard.state) {
		case KEYBOARD_STATE_RESET:
			KBD_CLK_DEASSERT();
			KBD_RESET_DEASSERT();
			keyboard.state = KEYBOARD_STATE_CLK_LOW;
			break;
		case KEYBOARD_STATE_CLK_LOW:
			row = KBD_Q0 | (KBD_Q1 << 1) | (KBD_Q2 << 2) | (KBD_Q3 << 3);
			if(keyboard.column & 1) {
				oldrow = keyboard.keystate[keyboard.column >> 1] >> 4;
				keyboard.keystate[keyboard.column >> 1] &= 0x0F;
				keyboard.keystate[keyboard.column >> 1] |= row << 4;
			} else {
				oldrow = keyboard.keystate[keyboard.column >> 1] & 0xF;
				keyboard.keystate[keyboard.column >> 1] &= 0xF0;
				keyboard.keystate[keyboard.column >> 1] |= row;
			}
			
			for(i = 0; oldrow != row; i++) {
				if((oldrow & 1) ^ (row & 1)) {
					keyboard_event_push(((oldrow & 1) << 7) | ((keyboard.column << 2) | i));
				}
				
				oldrow >>= 1;
				row >>= 1;
			}
			
			KBD_CLK_ASSERT();
			keyboard.state = KEYBOARD_STATE_CLK_HIGH;
			break;
		case KEYBOARD_STATE_CLK_HIGH:
			if(++keyboard.column == COLUMNS)
				keyboard.column = 0;
			KBD_CLK_DEASSERT();
			keyboard.state = KEYBOARD_STATE_CLK_LOW;
			break;
	}
}

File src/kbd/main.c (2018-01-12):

#include <stdint.h>
#include <stdbool.h>
#include <avr/interrupt.h>
#include <avr/io.h>
#include <avr/sleep.h>
#include "sleep.h"
#include "power.h"
#include "protocol.h"
#include "spi.h"
#include "keyboard.h"
#include "mouse.h"
#include "interrupt.h"

StatusRegister reg_status;
ControlRegister reg_control = {
	.keyboard_ie = true,
};

ISR(TIMER0_COMPA_vect) {
	keyboard_tick();
	mouse_tick();
	interrupt_assert();
}

void timer_init() {
	TCCR0A = 0xD; //Clear on compare, clk/1024
	TCNT0 = 0;
	OCR0A = 24;
	TIMSK0 = 0x2; //Interrupt on compare A
	
}

void timer_deinit() {
	TCCR0A = 0x0;
	TIMSK0 = 0x0;
	TCNT0 = 0;
}

int main() {
	power_init();
	for(;;) {
		cli();
		sleep_enable();
		sei();
		sleep_cpu();
		sleep_disable();
	}
}

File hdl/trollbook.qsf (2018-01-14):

# -------------------------------------------------------------------------- #
#
# Copyright (C) 1991-2009 Altera Corporation
# Your use of Altera Corporation's design tools, logic functions 
# and other software and tools, and its AMPP partner logic 
# functions, and any output files from any of the foregoing 
# (including device programming or simulation files), and any 
# associated documentation or information are expressly subject 
# to the terms and conditions of the Altera Program License 
# Subscription Agreement, Altera MegaCore Function License 
# Agreement, or other applicable license agreement, including, 
# without limitation, that your use is for the sole purpose of 
# programming logic devices manufactured by Altera and sold by 
# Altera or its authorized distributors.  Please refer to the 
# applicable agreement for further details.
#
# -------------------------------------------------------------------------- #
#
# Quartus II
# Version 9.0 Build 235 06/17/2009 Service Pack 2 SJ Web Edition
# Date created = 23:23:06  March 23, 2016
#
# -------------------------------------------------------------------------- #
#
# Notes:
#
# 1) The default values for assignments are stored in the file:
#		trollbook_assignment_defaults.qdf
#    If this file doesn't exist, see file:
#		assignment_defaults.qdf
#
# 2) Altera recommends that you do not modify this file. This
#    file is updated automatically by the Quartus II software
#    and any changes you make may be lost or overwritten.
#
# -------------------------------------------------------------------------- #


set_global_assignment -name FAMILY FLEX10KA
set_global_assignment -name DEVICE "EPF10K50VRC240-1"
set_global_assignment -name TOP_LEVEL_ENTITY trollbook
set_global_assignment -name ORIGINAL_QUARTUS_VERSION "9.0 SP2"
set_global_assignment -name PROJECT_CREATION_TIME_DATE "23:23:06  MARCH 23, 2016"
set_global_assignment -name LAST_QUARTUS_VERSION "9.0 SP2"
set_global_assignment -name EDA_SIMULATION_TOOL "ModelSim-Altera (VHDL)"
set_global_assignment -name EDA_OUTPUT_DATA_FORMAT VHDL -section_id eda_simulation
set_global_assignment -name USE_GENERATED_PHYSICAL_CONSTRAINTS OFF -section_id eda_blast_fpga
set_global_assignment -name DEVICE_FILTER_PACKAGE RQFP
set_global_assignment -name DEVICE_FILTER_PIN_COUNT 240
set_global_assignment -name DEVICE_FILTER_SPEED_GRADE 1
set_global_assignment -name MIN_CORE_JUNCTION_TEMP 0
set_global_assignment -name MAX_CORE_JUNCTION_TEMP 85
set_global_assignment -name ON_CHIP_BITSTREAM_DECOMPRESSION OFF
set_global_assignment -name RESERVE_ALL_UNUSED_PINS "AS INPUT TRI-STATED"
set_global_assignment -name FLEX10K_DEVICE_IO_STANDARD LVTTL/LVCMOS
set_global_assignment -name RESERVE_ALL_UNUSED_PINS_NO_OUTPUT_GND "AS INPUT TRI-STATED"
set_global_assignment -name MISC_FILE trollbook.dpf
set_location_assignment PIN_91 -to clk33
set_location_assignment PIN_158 -to vga_vsync
set_location_assignment PIN_159 -to vga_hsync
set_location_assignment PIN_161 -to vga_b[4]
set_location_assignment PIN_162 -to vga_b[3]
set_location_assignment PIN_163 -to vga_b[2]
set_location_assignment PIN_164 -to vga_b[1]
set_location_assignment PIN_166 -to vga_b[0]
set_location_assignment PIN_167 -to vga_g[5]
set_location_assignment PIN_168 -to vga_g[4]
set_location_assignment PIN_169 -to vga_g[3]
set_location_assignment PIN_171 -to vga_g[2]
set_location_assignment PIN_172 -to vga_g[1]
set_location_assignment PIN_173 -to vga_g[0]
set_location_assignment PIN_174 -to vga_r[4]
set_location_assignment PIN_175 -to vga_r[3]
set_location_assignment PIN_191 -to vga_r[2]
set_location_assignment PIN_187 -to vga_r[1]
set_location_assignment PIN_184 -to vga_r[0]
set_location_assignment PIN_127 -to vga_den
set_location_assignment PIN_181 -to vga_pwm
set_location_assignment PIN_23 -to vga_pwr
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

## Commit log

2014-11-14 modules for kicad: processor, cpld, co-processor, sram
    [trollbook.kicad_pcb, trollbook.sch]
2014-12-07 routed address and data lines between cpu, fpu, rom, cpld
    [trollbook.sch]
2014-12-11 routed sram, dram
    [trollbook.kicad_pcb, trollbook.sch]
2014-12-12 moved sram closer to cpu
    [trollbook.kicad_pcb, trollbook.sch]
2014-12-12 lcd connector, vga dac
    [trollbook.kicad_pcb, trollbook.sch]
2014-12-16 3d models
    [trollbook.kicad_pcb]
2015-01-15 aaaaawww yeeeaaaahhh
    [trollbook.kicad_pcb, trollbook.sch]
2015-01-15 capacitors, capacitors everywhere
    [trollbook.kicad_pcb, trollbook.sch]
2015-01-15 fixed some erc/drc violations
    [trollbook.kicad_pcb, trollbook.sch]
2015-01-15 ground plane stitching
    [trollbook.kicad_pcb]
2015-02-07 fixed a couple of voltage issues
    [trollbook.kicad_pcb, trollbook.sch]
2015-02-11 added rpack 3d model
    [trollbook.kicad_pcb]
2015-02-17 replaced ram footprint with the correct one
    [trollbook.kicad_pcb]
2015-02-17 lotsa 3d models :o
    [trollbook.kicad_pcb]
2015-08-25 added 040 cpu to rev2
    [trollbook-rev2.kicad_pcb, trollbook-rev2.sch]
2015-08-26 cpu footprint
    [trollbook-rev2.kicad_pcb, trollbook-rev2.sch, trollbook.kicad_pcb]
2015-08-26 added fpga
    [trollbook-rev2.kicad_pcb, trollbook-rev2.sch]
2015-09-02 fixed clearance, added ram
    [trollbook-rev2.kicad_pcb, trollbook-rev2.sch]
2015-09-02 track width
    [trollbook-rev2.kicad_pcb]
2015-09-09 started connecting processor to glue
    [trollbook-rev2.kicad_pcb, trollbook-rev2.sch]
2015-09-09 added oscillator lib
    [trollbook-rev2.kicad_pcb]
2015-09-29 connectec cpu control signals, spi stuff
    [trollbook-rev2.kicad_pcb, trollbook-rev2.sch]
2015-10-23 cpu control signals, vga dac
    [trollbook-rev2.kicad_pcb, trollbook-rev2.sch]
2015-12-17 almost done
    [trollbook-rev2.kicad_pcb, trollbook-rev2.sch]
2016-01-21 now only the capacitors left
    [trollbook-rev2.kicad_pcb, trollbook-rev2.sch]
2016-02-02 added external interrupt header
    [trollbook-rev2.kicad_pcb, trollbook-rev2.sch]
2016-02-10 aligned pin headers
    [trollbook-rev2.kicad_pcb]
2016-02-21 finished all routing, only minor touch-ups left
    [trollbook-rev2.kicad_pcb, trollbook-rev2.sch]
2016-02-22 touched up silkscreen a bit
    [trollbook-rev2.kicad_pcb, trollbook-rev2.sch]
2016-02-24 minor fixes and gerbers
    [trollbook-rev2-B.Cu.gbr, trollbook-rev2-B.SilkS.gbr, trollbook-rev2-Edge.Cuts.gbr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]
2016-02-29 added pcb logo
    [trollbook-rev2.kicad_pcb, trollbook-rev2.sch]
2016-03-03 corrected solder mask minimum width, now there is solder stop everywhere
    [trollbook-rev2-B.Cu.gbl, trollbook-rev2-B.Mask.gbs, trollbook-rev2-B.SilkS.gbo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]
2016-03-04 correct cpu name on silk screen
    [trollbook-rev2.kicad_pcb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]
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2016-03-24 added all pins to pin planner
    [trollbook-pins.csv]
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2016-03-29 this does not work, tri state drivers need to be top level
2016-03-30 added proper data bus driving, reset, simple test bench
    [trollbook.qsf]
2016-03-30 testbench correctly testing power on reset
2016-03-31 replaced nop with branch to generate valid reset vectors
    [trollbook.qsf]
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2016-04-03 llram access from cpu is probably glitchy as fuck but might just work..
    [trollbook.qsf]
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2016-04-15 fixed some issues with bus and uart, still not working properly
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2016-09-08 fixed failed spi merge
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2016-09-09 fixed reading MISO in wrong bit order
    [main.c]
2016-09-09 fixed SPI fo rels
    [main.c]
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2016-09-20 fixed bug, printing hex with highest bit -> FF
    [main.c]
2016-09-23 fix stage1 spi code push/pop order
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2016-10-09 fixes broken cache line fetches from llram
    [main.c]
2016-11-02 started on peripheral board
    [audio.sch, keyboard.sch, mouse.sch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]
2016-11-05 added tac switch footprint
    [audio.sch, keyboard.sch, mouse.sch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]
2016-11-06 added button 3d model
    [audio.sch, keyboard.sch, mouse.sch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]
2016-11-06 added keyboard scanning logic
    [keyboard.sch, mouse.sch, peripheral-board.kicad_pcb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]
2016-11-06 added peripheral board bus header
    [audio.sch, keyboard.sch, peripheral-board.kicad_pcb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]
2016-11-06 keyboard switches and diodes placed
    [audio.sch, external.sch, keyboard.sch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]
2016-11-08 routed keyboard
    [audio.sch, external.sch, keyboard.sch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]
2016-11-09 some more keyboard stuff fit on this side..
    [audio.sch, external.sch, keyboard.sch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]
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2017-01-10 fixed loading incorrect page sizes in elf loader
    [main.c]
2017-01-16 added some audio circuitry
    [audio.sch, external.sch, keyboard.sch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]
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2017-01-19 read correct boot switch bit
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2017-02-08 added battery charger schematic
    [audio.sch, battery.sch, external.sch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]
2017-02-13 added audio jack
    [audio.sch, battery.sch, external.sch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]
2017-02-14 added loudspeaker
    [audio.sch]
2017-02-14 audio circuitry
    [audio.sch, battery.sch, external.sch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]
2017-02-14 power supply component placement
    [audio.sch, battery.sch, external.sch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]
2017-02-15 audio components placement
    [audio.sch, battery.sch, external.sch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]
2017-02-15 routed spi
    [audio.sch, external.sch, keyboard.sch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]
2017-02-16 routed audio circuitry
    [peripheral-board.kicad_pcb, peripheral-board.sch, power.sch]
2017-02-16 added linear 3v3 reg for keyboard micro
    [audio.sch, external.sch, keyboard.sch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]
2017-02-16 keyboard files
    [keyboard_frame.fcstd, keycap.fcstd]
2017-02-16 routed traces.
    [audio.sch, battery.sch, external.sch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]
2017-02-16 routed misc signals to micro
    [audio.sch, external.sch, keyboard.sch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]
2017-02-18 misc traces, headphone jack 3d
    [FCR1295.step, audio.sch, battery.sch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]
2017-02-18 sd card 3d model
    [SD-RSMT-2-MQ.step, peripheral-board.kicad_pcb]
2017-02-18 added expansion port 3d model
    [10056847-XY1LF.step, peripheral-board.kicad_pcb]
2017-02-19 fixed various drc errors
    [peripheral-board.kicad_pcb, peripheral-board.sch, sd.sch]
2017-02-19 minor fixes
    [audio.sch, external.sch, peripheral-board.kicad_pcb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]
2017-02-19 connected 3v3 net
    [keyboard.sch, peripheral-board.kicad_pcb]
2017-02-19 psp nub 3d model
    [peripheral-board.kicad_pcb, pspnub.step]
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2017-02-20 added speaker and battery connectors
    [audio.sch, external.sch, peripheral-board.kicad_pcb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]
2017-02-20 peripheral board all done o____O
    [audio.sch, external.sch, keyboard.sch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]
2017-02-21 touched up silkscreen
    [peripheral-board.kicad_pcb]
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2017-04-05 mouse connected to adc pins
    [audio.sch, external.sch, mouse.sch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]
2017-04-05 removed old gerbers
    [peripheral-board-B.Cu.gbr, peripheral-board-B.Mask.gbr, peripheral-board-B.SilkS.gbr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]
2017-04-05 moved power supply capacitor to accomodate larger battery
    [peripheral-board.kicad_pcb]
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2017-04-25 fixed faulty schematic in battery balancer
    [battery.kicad_pcb, battery.sch]
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2017-04-26 reset spi clockdiv
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2017-05-07 fixes to low-res mode
    [main.c]
2017-05-08 minor fixes to peripheral board
    [audio.sch, external.sch, keyboard.sch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]
2017-05-08 more audio circuit fixes
    [audio.sch, external.sch, keyboard.sch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]
2017-05-17 fixed sdram timing issues by disabling burst writes
    [input.c, trollbook.qsf]
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2018-01-19 use relative path for pcb 3d models
    [trollbook-rev2.kicad_pcb]
2018-04-22 changed timers to common prescaler + 16 bit to save space
    [timer-regs.ods]
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2021-12-11 vga hdl implement palette writes
    [vga-regs.ods]
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
